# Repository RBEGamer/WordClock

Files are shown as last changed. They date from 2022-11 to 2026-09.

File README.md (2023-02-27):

# Wordclock

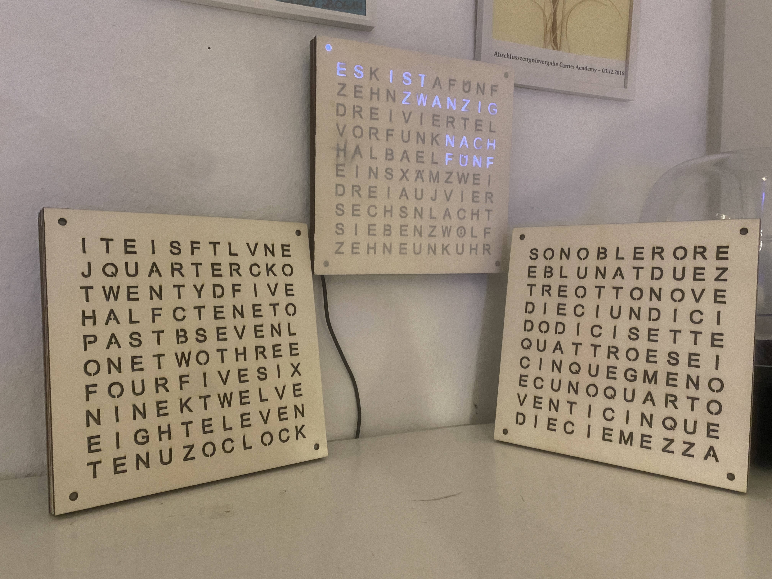
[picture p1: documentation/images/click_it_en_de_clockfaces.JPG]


## FEATURES
Simple easy to build tabletop wordclock with many features:

* different clockfaces and languages
* different colormodes (coldwhite, warmwhite, 2x rainbow)
* RP2040 based
* ambient light sensor
* temperature sensor
* eu summertime support
* optional wifi based sync and control

## IMPLEMENTED LANGUAGES

* GERMAN
* ENGLISH
* ITALIAN

### POSSIBLE LANGUAGES

* SPANISH
* DUTCH

## USER-MANUAL

complete

### POWER UP

Connect the clock using its Micro-USB port on the back a USB power source like a PC or USB wallplug.
After a few seconds the clock lights up, depending on the configuration it may be that the brightness is set very low or the fontface is set incorrectly. To make these settings the web configuration can be used. Please follow the steps below to access the configuration webui.

### CONNECT CLOCK TO WIFI

To sync up the current time using NTP or setup the fontface or colors, connect the clock to a existing 2.4Ghz Wifi network.
After startup the clock check if the previous setup network exists. 

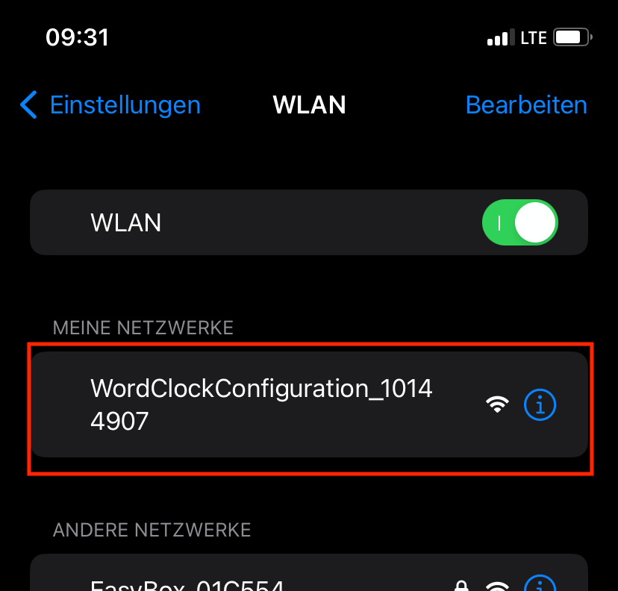
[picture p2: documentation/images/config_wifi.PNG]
config_wifi


If not, the clock will open its own Wifi with the SSID `WordClockConfiguration_%ID%` (`%ID%` is the ID printed on the back of the clock).
After connecting, an captive portal should open, or by open the IP `192.168.4.1` in a web browser to set up the new Wifi.

**NOTE**
The configuration wifi will be disabled after one minute, so if it is not visible power cycle the board.

**NOTE**
If the clock cannot connect to the configured WLAN (not found, or invalid credentials,...), the configuration accesspoint is opened again.

### ACCESS CONFIGURATION WEBUI

After configuring the wifi, you can access the clock-configuration webpage using its DHCP address (see your router or nmap) or use the clocks mDNS adress `http://wordclock%%ID%%.local` with `%%ID%%` is the ID printed on the back of the clock, like: `http://wordclock10144907.local`.

**NOTE** After a wifi connection is established (power up, power cycle), the clock shows it on its display by means of the words. here the ip blocks are shown with the hours and the dot by using dark switching 0 or 12.

So `192.168.178.4` results in the following word order:
`one nine two  (pause)(dark 0/12)(pause) one six eight (pause)(dark 0/12)(pause) one seven eight (pause)(dark 0/12)(pause) four`

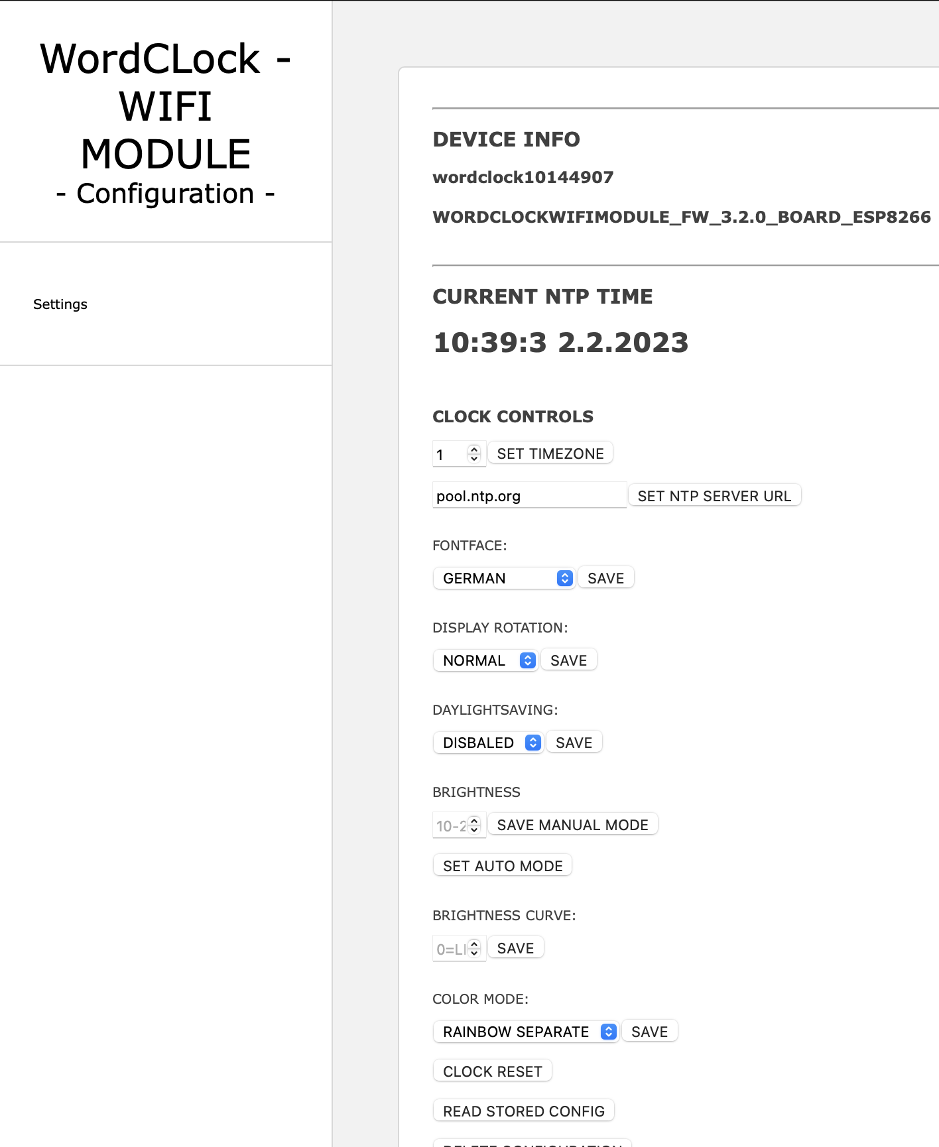
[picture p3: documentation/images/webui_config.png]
webui_config


### FIRMWARE UPDATE

It is possible to update the software of the clock.
This adds new features like new languages and general bug fixes.
The software of the `RP2040` main processor can be updated directly via the USB interface on the back.
To perform the update, a small button called `QBOOT` must be pressed and held while the watch is turned off and connected to a PC.

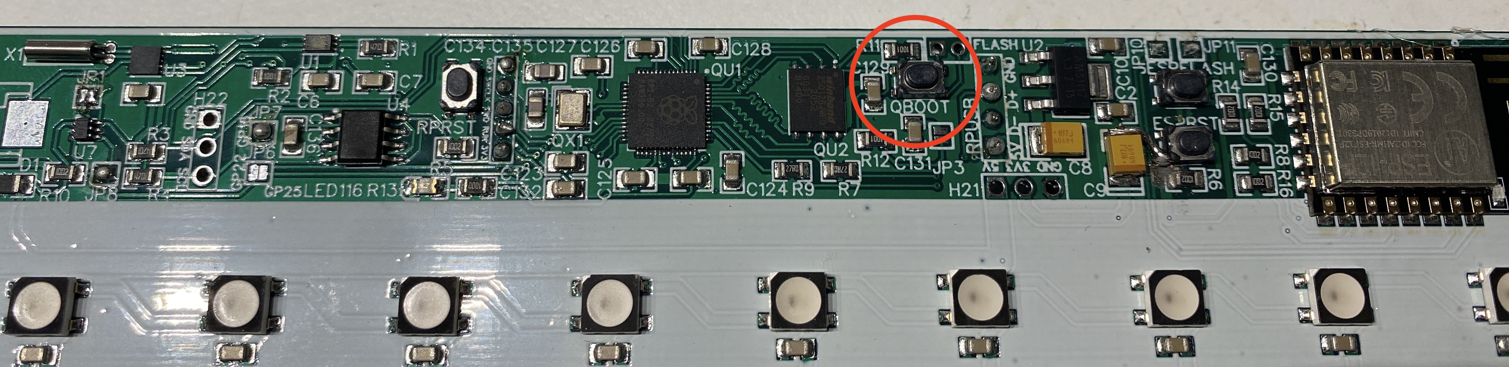
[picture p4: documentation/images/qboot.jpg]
qboot_button


You can press the button even when the clock is assembled.
The button is accessible through the cutout on the top of the clock near the USB port.

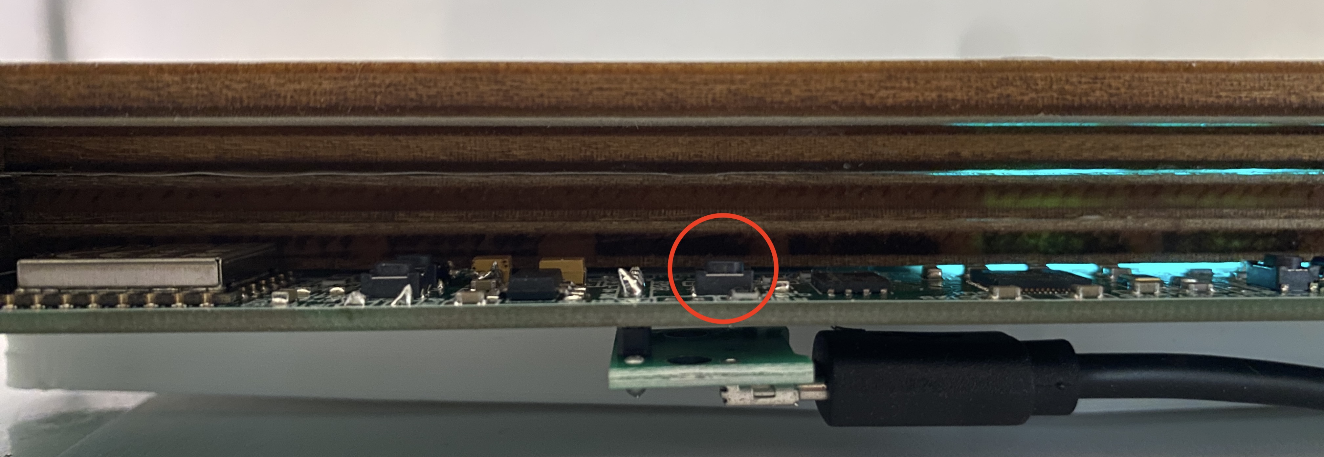
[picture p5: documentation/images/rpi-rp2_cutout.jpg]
rpi-rp2_cutout


Now a new removable drive with the name `RP-BOOT` should appear.
Now copy (or drag&drop) the `.u2f` update file to the drive.
After the copy process is complete, the drive disappears automatically and the clock restarts.
If the update fails, you can do it again by repeating the steps.

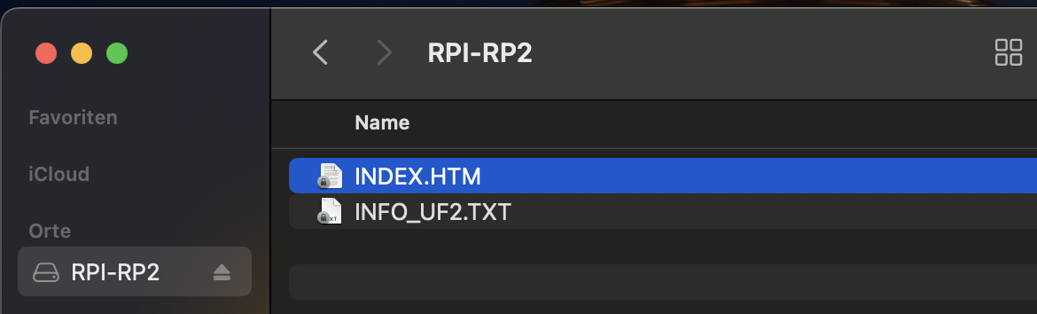
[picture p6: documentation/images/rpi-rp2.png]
rpi-rp2


**NOTE**
Check the firmware version after an update using the [STATUS-CODES](#status-codes).

**NOTE**
On MacOS drag&drop installation can fail, so please try `$ cp ./WORDCLOCK_Vx_RP2040_x.y.z_Release.uf2 /Volumes/RPI-RP2/` from the Terminal-App instead.

**NOTE**
Instead of reconnecting the USB cable, there is an other button called `RPRST` which can be pressed once, while keep holding the `QBOOT` button.

#### DOWNLOAD FIRMWARE UPDATE
Please identfy the clock hardware version, which is printed on the back of the clock or use the [STATUS-CODES](#status-codes) display.

##### STATUS CODES
Directly after startup, the clock shows some version information about the hardware revision and used software.
This information is language-independent and is displayed in the form of individual illuminated LEDs.
On the following picture their meaning can be determined.

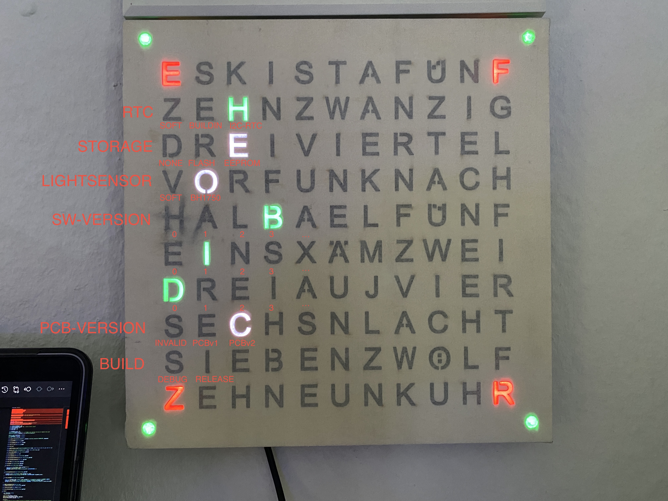
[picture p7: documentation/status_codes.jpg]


Information from example above:

* Hardware-Revision: 2 (`PCBv2`) so use `WORDCLOCK_V2_*.uf2` firmware files
* RTC: `I2C (DS17307)`
* Configuration-Storage: `EEPROM`
* Lightsensor: `BH1750`
* Software-Version: 3.1.0 (test), please use stable `Release` firmware

To download the latest software, please see the [Firmware-Releases](https://github.com/RBEGamer/WordClock/releases) page.
For the current `V2` clocks, use the latest firmware file: `WORDCLOCK_V2_RP2040_RP2040RTC_x.y.z_Release.uf2`.

For the `V1` clocks, use the archived firmware: `WORDCLOCK_V1_RP2040_3.1.0_Release.uf2`.

**Note**
If `RTC`, `Lightsensor` and `Storage` are set to `SOFT` and `None`/`FLASH` please use firmware `WORDCLOCK_Vx_NOI2C_*.u2f`.
* RTC: `SOFT`
* Configuration-Storage: `FLASH` or `NONE`
* Lightsensor: `SOFT`

[WORDCLOCK_V2_RP2040_NOI2C_3.2.2_Release.uf2](https://github.com/RBEGamer/WordClock/releases/download/v3.2.2/WORDCLOCK_V2_RP2040_NOI2C_3.2.2_Release.uf2)

### FIRMWARE CUSTOMIZATION

It is also possible to make your own adjustments to the clock's firmware, e.g. to add your own languages or animations.

It is recommended to use Visual Code with the following plugins as the editor, since the project already has all the necessary settings and also a debug environment configured. This makes it easy to get started.

* `C/C++` by `Microsoft`
* `Cortex-Debug` by `marus25` 

The complete firmware of the RP2040 main processor is available in the `src/base/wordclock/src` folder.
If you want to develop your own fontface, see the examples in  `wordclock_faceplate` and the `wordclock_faceplate_template.*` files.

#### BUILDING THE FIRMWARE YOURSELF

```bash

$ git clone --depth 1 https://github.com/RBEGamer/WordClock.git ~/WordClock
$ cd ~/WordClock/base/wordclock/
# UPDATE CMAKE PATHS
$ rm -Rf build CMakeCache.txt CMakeFiles elf2uf2 generated pioasm WORDCLOCK_* build_u2f
# see board folder for available PCB-Revisions
# for example to build the firmware for a PCBv2 use WORDCLOCK_V2_RP2040_RP2040RTC
## RELEAE
$ cmake -DCMAKE_BUILD_TYPE=Release -DWORDCLOCK_BOARD=WORDCLOCK_V2_RP2040_RP2040RTC .
## DEBUG
$ cmake -DCMAKE_BUILD_TYPE=Debug -DWORDCLOCK_BOARD=WORDCLOCK_V2_RP2040_RP2040RTC .
PICO_SDK_PATH is ~/WordClock/src/base/pico-sdk
Defaulting PICO_PLATFORM to rp2040 since not specified.
Defaulting PICO platform compiler to pico_arm_gcc since not specified.
PICO compiler is pico_arm_gcc
-- The C compiler identification is GNU 10.3.1
-- The CXX compiler identification is GNU 10.3.1
-- The ASM compiler identification is GNU
-- Found assembler: /opt/homebrew/bin/arm-none-eabi-gcc
Build type is Release
PICO target board is WORDCLOCK_V2_RP2040_RP2040RTC.

# BUILD
# on first build the pico-sdk will be downloaded
# the result should be a WORDCLOCK_V2_RP2040_RP2040RTC_3.2.3_Debug.uf2
$ make -j8
[ 97%] Linking CXX executable WORDCLOCK_V2_RP2040_RP2040RTC_3.2.3_Debug.elf
[100%] Built target wordclock

# FLASH
# you can use the drag&drop method to install the firmware or use the pico-tool with a usb connected clock.
# see flash_release.sh or flash_release.sh
$ ../picotool/picotool load -f *.uf2 && ../picotool/picotool reboot
```

**NOTE**
To build the a new firmware relase, for all clock hardware-revisions you can use the `build_all.sh` script.
It builds the `.u2f` for each board definition located in the `board` folder and stores the build artefacts in `build_u2f`.

## BUILD YOUR OWN CLOCK

### PARTS

The latest version of the clock is currently `v2` so please replace `vX` with `v2` in the following instructions.

#### ELECTRICAL

* 1x ASSEMBLED PCB - `./src/pcb/vX`
* 1x MicroUSB to DIP breakout or USB Cable with open leads

#### MECHANICAL

##### LASERCUT LAYERS 
**See `./src/lasercut` for cutting instructions**

All needed drawings are located in the `./src/lasercut/vX/layers_seperated` directory:

* 1x - BACKCOVER `3_backcover_layer` - >=3mm plywood (or plexiglas)
* 1x - SPACER `2_lightguide_layer` - >=3mm plywood (or plexiglas, but its hidden)
* 1x - SPACER `2_lightguidehexnut_layer` - >=3mm plywood (or plexiglas, but its hidden)
* 1x - FACEPLATE `1_text<LANGUAGE>_layer` - plexiglas, plywood >220x220mm 1mm

##### [OPTIONAL] 3D PRINTED STANDS

All needed files are located in the `./src/3d_print/` directory:

####### TABLESTAND
* 1x - TABLESTAND `wordclock_tablestand.stl`

####### WALLMOUNT
* 1x - WALLMOUNT `wordclock_wallmount.stl`

#### OTHER

* sandwich paper - as additional semi transparent diffusor ontop of the leds
* woodglue - to glue spacers together
* isopropanol - plexiglas cleaning before gluing

#### TOOLS

* lasercutter / cnc for cutting wood / plexiglas with working-area of at least 220mmx220mm
* 3d rpinter can be used to print the faceplates and spacers(conversion from svg-> 3mm stl is needed)

#### ASSEMBLY INSTRUCTIONS

##### 0 - INSERT HEXNUTS
Place some M4 nuts in the hexnut cutouts in the `lightguidehexnut` plate.
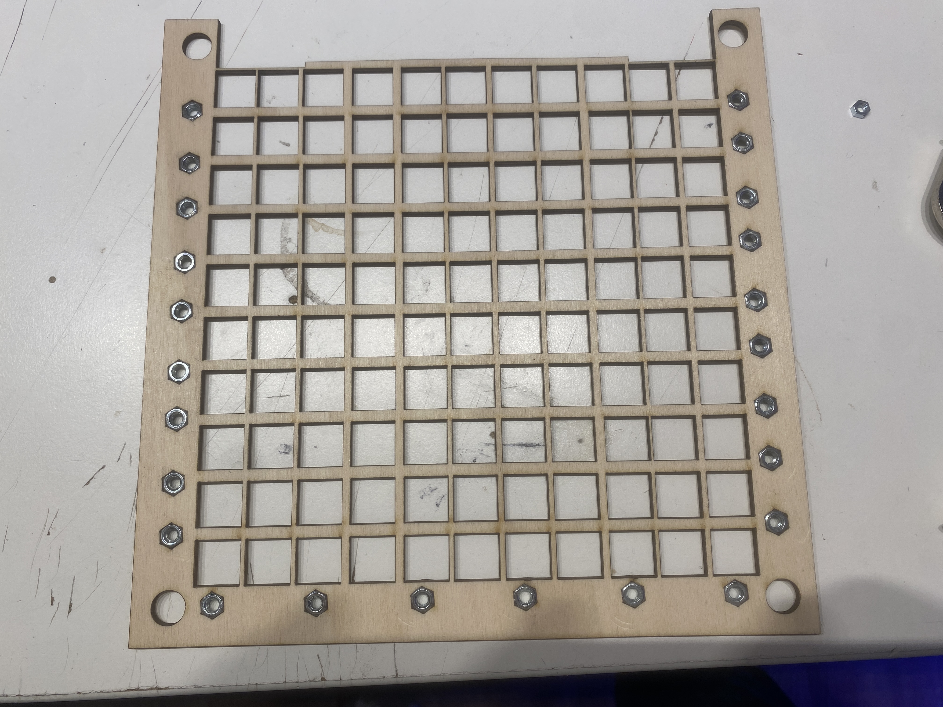
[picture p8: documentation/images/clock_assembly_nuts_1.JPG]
clock_assembly_nuts_1


##### 1 - GLUE SPACERS TOGEHTER
Glue the spacers `lightguidehexnut` and `lightguide` using woodglue togehter.
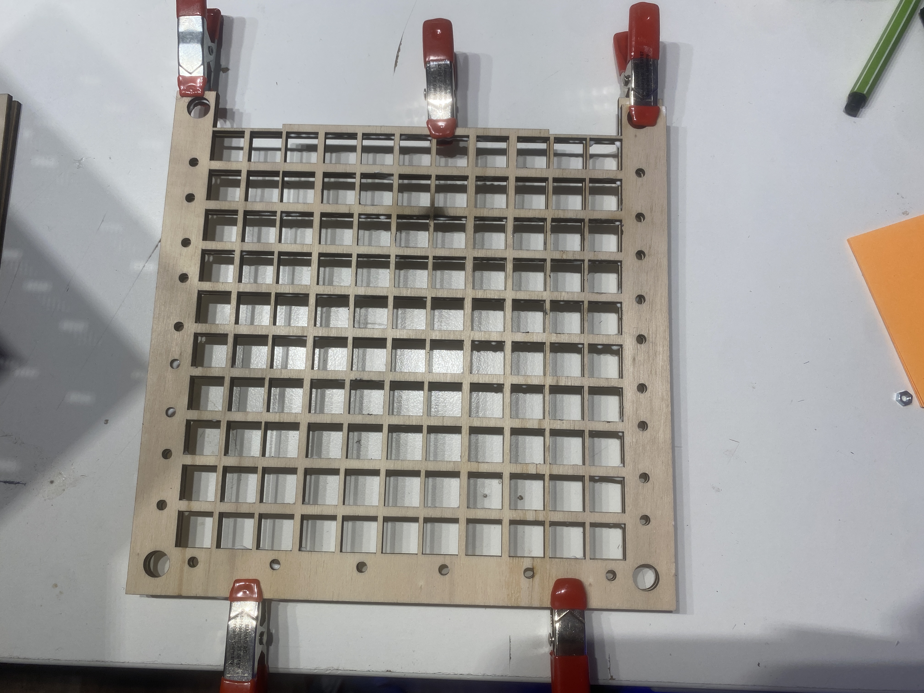
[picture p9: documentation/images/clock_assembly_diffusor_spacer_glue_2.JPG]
clock_assembly_diffusor_spacer_glue_2


##### 2 - ADD  DIFFUSOR
Place and glue the sandwichpaper ontop the the `lightguidehexnut` layer.
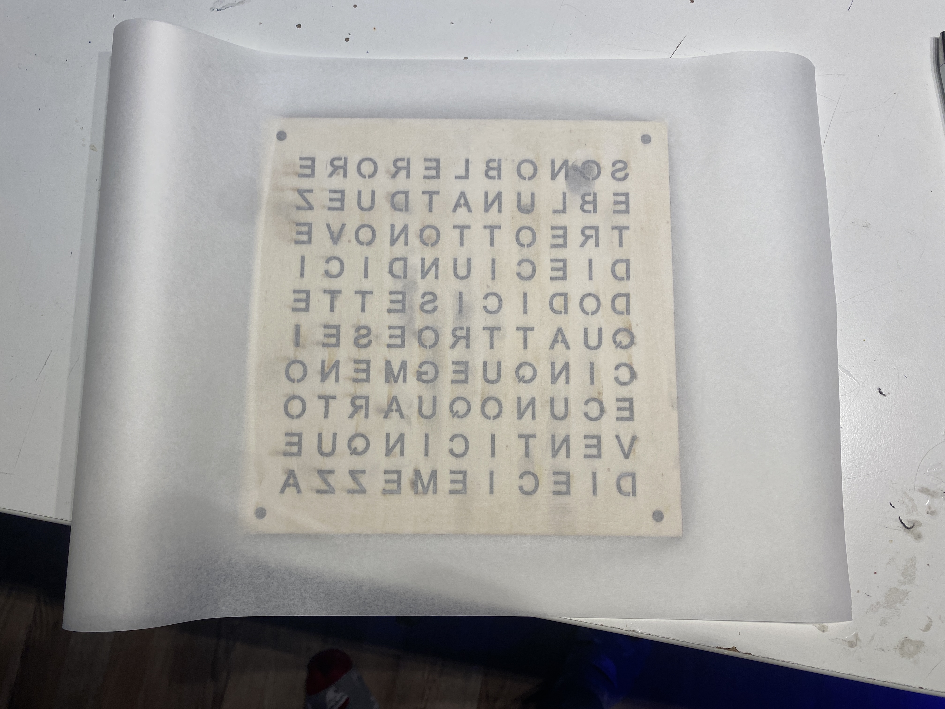
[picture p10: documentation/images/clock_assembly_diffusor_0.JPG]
clock_assembly_diffusor_0

 
##### 3 - ADD FACEPLATE
Glue the `FACEPLATE` ontop of the sandwhichpaper, make sure that the cutout in the spacers is the top of the clock.
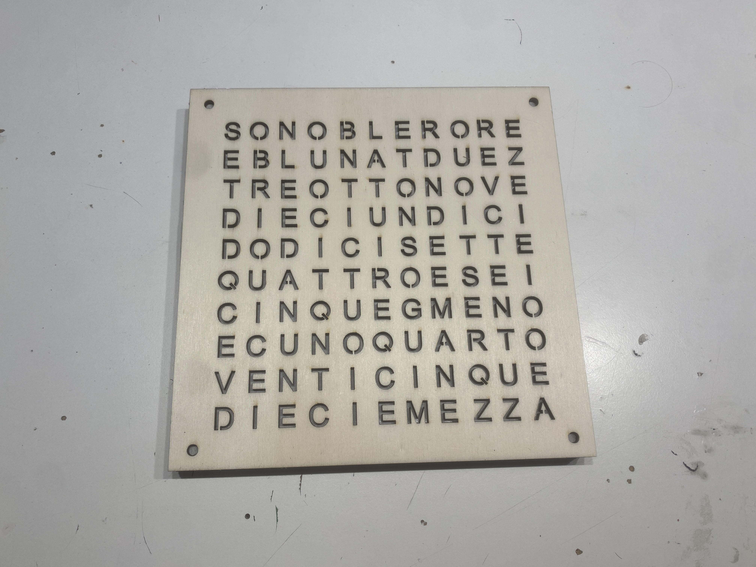
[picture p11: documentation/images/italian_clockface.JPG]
italian_clockface


##### 4 - ASSEMBLY
Place the glued fontplate/spacer assembly ontop of the PCB and place the `BACKCOVER` on the back of the PCB.
Use the four M4 screws in the holes in the corners, to screw anything together.
clock_assembly_diffusor_0

##### 5 - WALLMOUNT / TABLESTAND [OPTIONAL]

Mount the 3D-printed `wallmount` or `tablestand`.

###### TABLESTAND
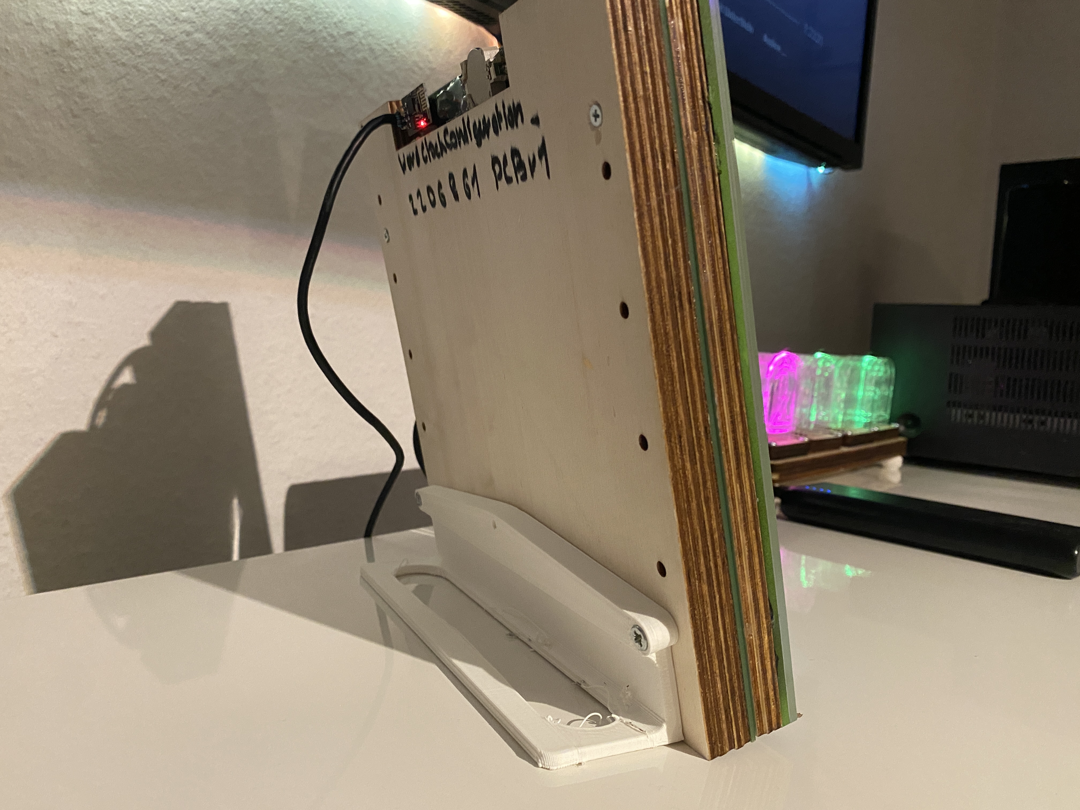
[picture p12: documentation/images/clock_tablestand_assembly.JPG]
clock_tablestand_assembly


###### WALLMOUNT
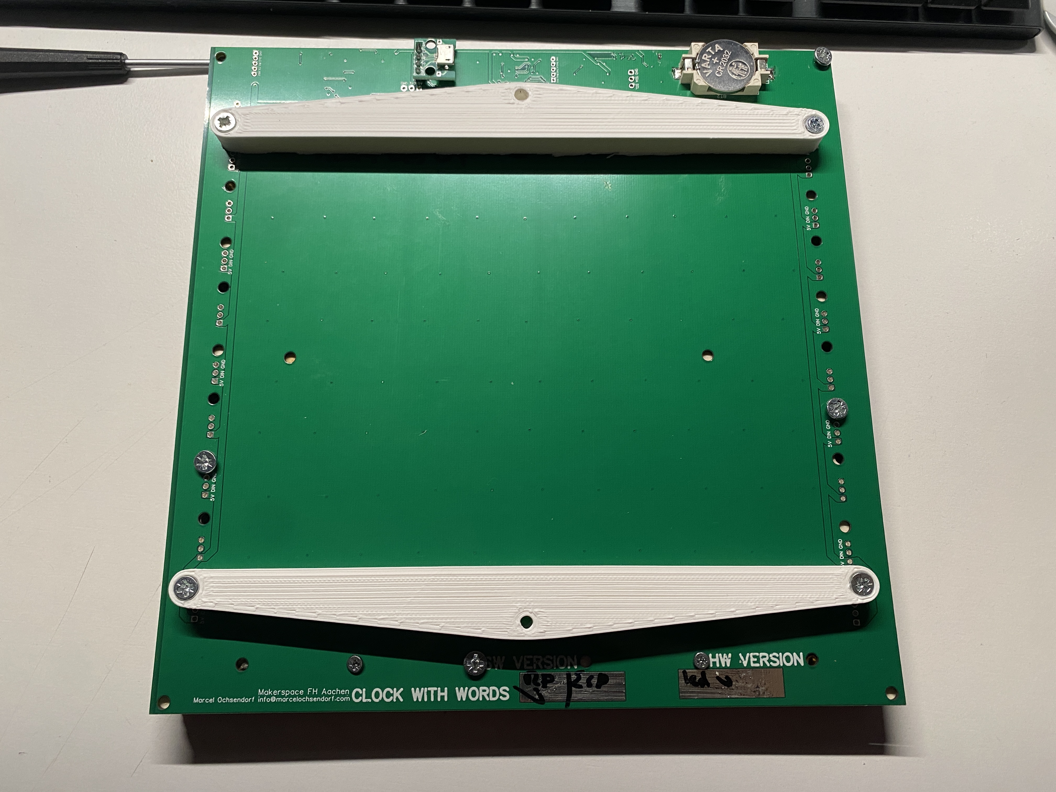
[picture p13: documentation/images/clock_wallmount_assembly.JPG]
clock_wallmount_assembly


##### 6

Flash the firmware to the clock using the [USER-MANUAL](#user-manual)

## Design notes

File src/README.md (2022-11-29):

# SRC

* `base` - main RP2040 software
* `pcb` -  pcb with 11x10 led matrix
* `lasercut` - all lasercut files (`svg`, `dfx`), cad files
* `wifiextention` - softeare for `esp8266` wifimodule

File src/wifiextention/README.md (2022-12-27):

# WIFIMODULE - ESP8266 SOFTWARE

This folder contains the software for the optional `ESP8266-12F` (PCBv2) or `ESP8266-01` (PCBv1).
Also compatible with `ESP32`.
The module allows to edit settings and sync time over a ntp server.

Copy the content of the `3rd_party` folder into the `Arduino`-Libraries folder.

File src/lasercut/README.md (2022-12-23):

# LASERCUT

## PCBv1

Glue the wooden pieces together in the following order: 

* 1x - `drawing_chars`
* 3x - `drawing_lightguide`
* `--- PCB ---`
* 2x - `drawing_back`

## PCBv2

the V2 lasercutting files are loacated in the `./v2` folder.
The main source files is the single `drawing.svg` file, which contains several numbered layer object in it.
Objects in `[]` can be ignored, these are used for reference linke the `[PCBv2]` image of the PCB.

Each layer object in the svg will be used to cut one piece for the clock.
Some layers are needed multible times and will be glued together to form a higher single layer.

### FACEPLATE (PLEXIGLAS)

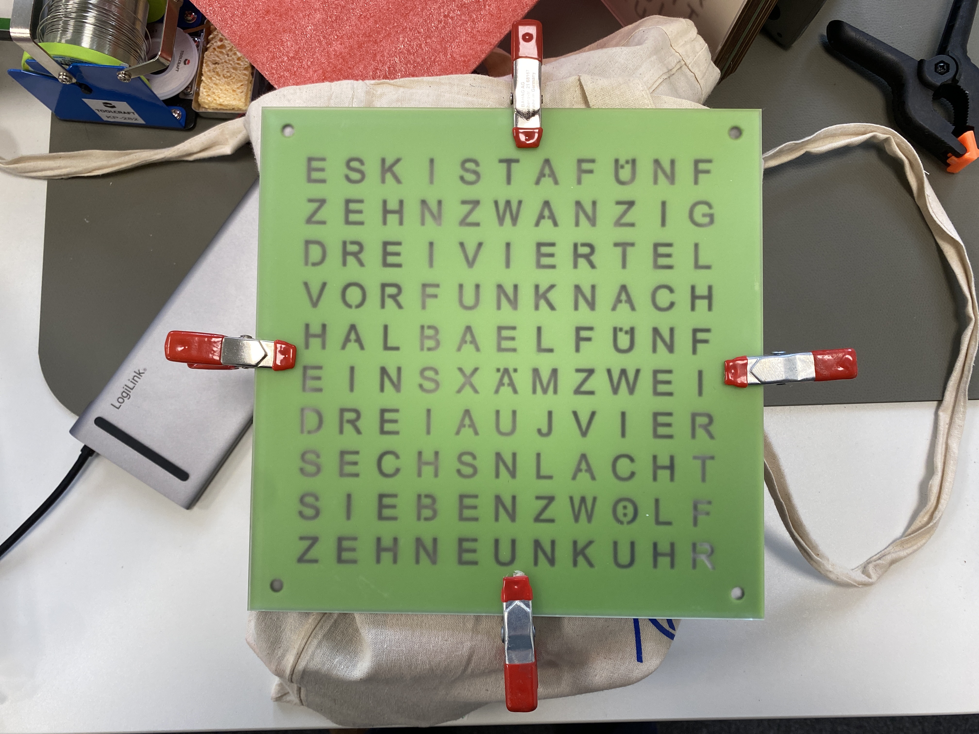
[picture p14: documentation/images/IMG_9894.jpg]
topcover


* 1x - `0_opaque_layer` - this is the semi-transparent toplayer plexiglas
* 1x - `1_<LANGUAGE>_layer` - this is the textlayer with the cut out characters

 Clean (isopropanol), place and clamp! the `0_opaque_layer` and `1_<LANGUAGE>_layer` layer ontop of each other and use the `ACRIFIX Plexiglas glue` to fill the minute dot holes with the glue and let it dry for at least 8h.

### LIGHTGUIDE (WOOD)

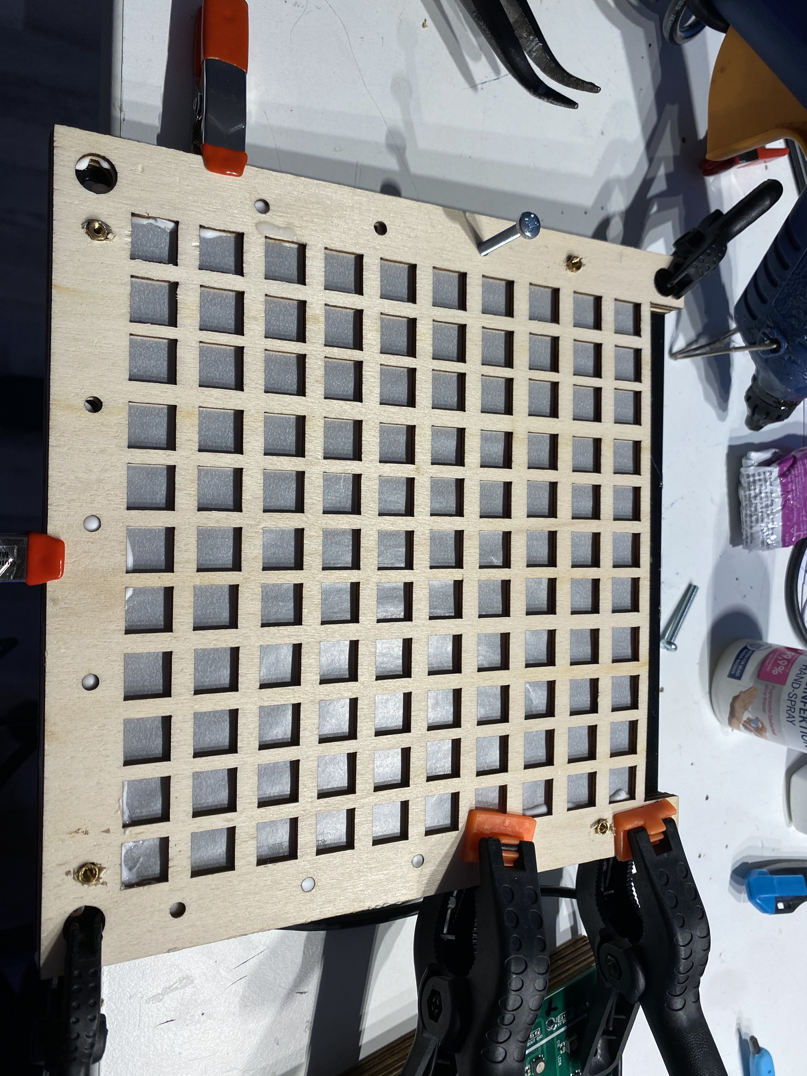
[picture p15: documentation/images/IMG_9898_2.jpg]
lightguide


* 1x - `2_lightguidehexnut_layer` - its use to get some space between the leds and the text faceplate
* 2x - `2_lightguidenormal_layer` - its use to get some space between the leds and the text faceplate

Glue the two `2_lightguidenormal_layer` sheets together and before adding the third one add one sheet of sandwich paper/ semi transparent diffusor between them.
In the end this additional diffusor sit ontop of the leds with one lightguide seperating them.
You can place screws in the holes to align everything during curing.

### BACKCOVER

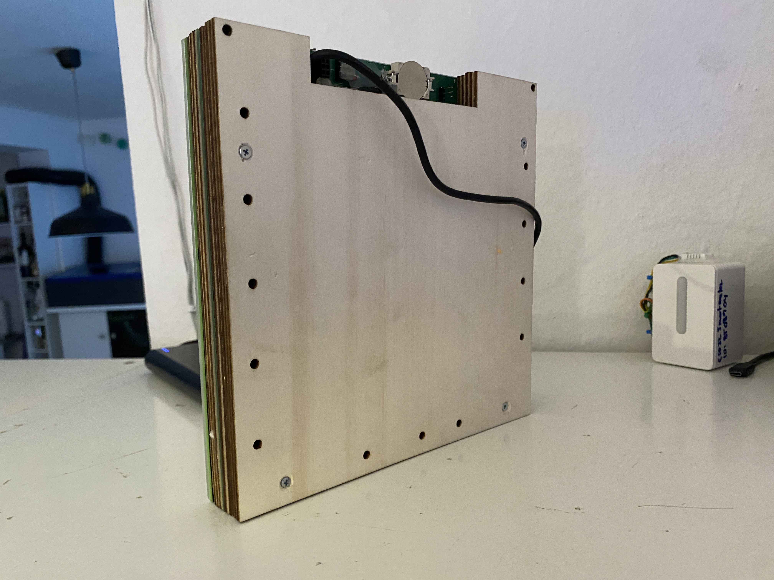
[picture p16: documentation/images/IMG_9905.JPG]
backcover


* 1x - `3_backcover`

## STACK

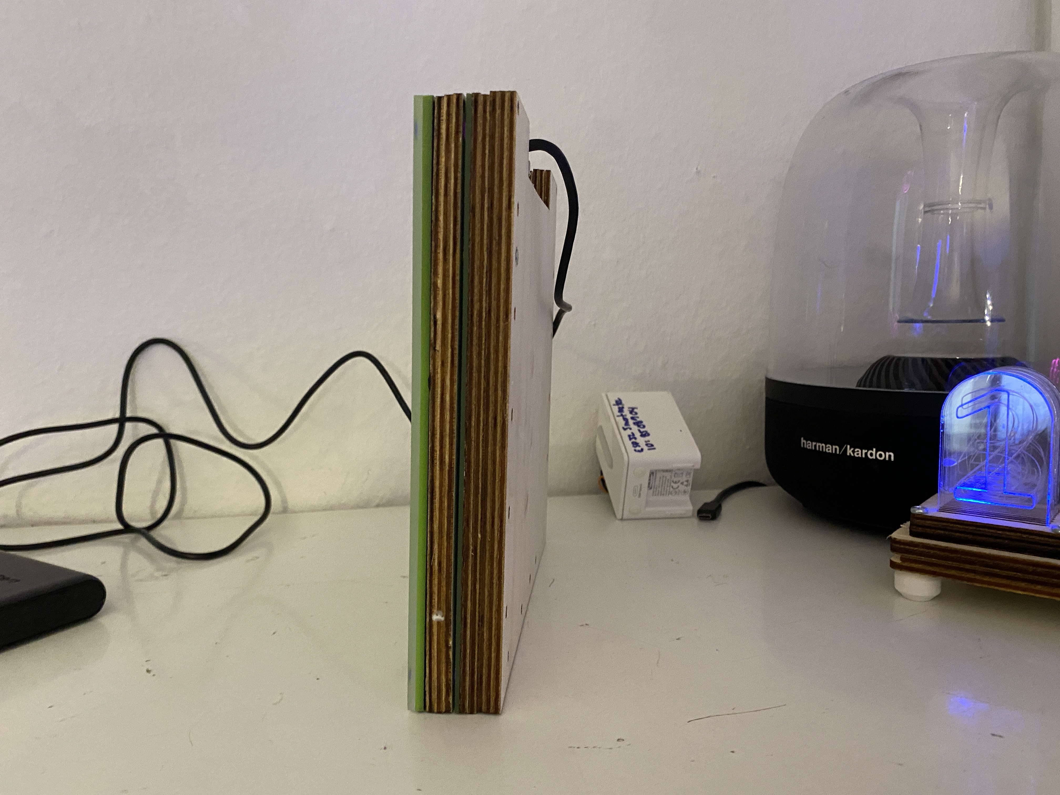
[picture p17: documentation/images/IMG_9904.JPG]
stack


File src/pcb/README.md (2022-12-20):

# PCB

## V1

The first revision of the wordclock pcb is working but has some issues!
Please see PCB version 2, with all fixed issues and further features.

### ISSUES

* r12 produces flash issues
* esp8266-01 creates space issues with usb connector
* levelshifter for ws2812 not working relilable with 800khz
* rtc not readlable for i2c, power issue => can be resolved by connecting VCC of the DS1307 chip to 5V.

### JUMPER SETTINGS

In order to make this version of the pcb compatible with the current firmware version, please use the following jumper settings:

* !!! REMOVE TRANSISTOR Q2 !!!
* !!! REMOVE RESISTOR R12 !!!
* bridge JP1
* bridge JP7 (GP16)
* jumper H23 (middle+upper, near JP2)

### WIFI-MODULE

If you want to use the ESP8266-01 you have to put a missing 10K (or bridge) the pins VCC and EN (CH-PD) on the module in order to enable the module.
This resistor is missing on the PCB.

## V2

### CHANGES

* replace ds1307 with pcf85263a
* remove R12 (resolve flash access issues)
* added esp8266-12f (replacement for esp8266-01)
* removed transistor base levelshifter (replaced with txb0101)
* added rpi rst pullup (optional)
* moved coincell to toplayer
* added loadcaps 10pf for 12mhz osc
* added rst/run to swd connector
* removed german wordclock faceplate from the back of the pcb
* added i2c eeprom to avoid flash as settings store

### JUMPER SETTINGS

* JP10 -> ESP_TX
* JP11 -> ESP_RX
* JP7 -> GP16
* (JP1) -> TBX01-OE  
* JP6 -> GP22

Use `WORDCLOCK_V2_RP2040.h` with this jumper settings:

* JP7
* JP1
* JP8
* JP10
* JP11

## ISSUES

* with the current v2 lasercut part the position of C121 is not ideal
* led alignment is not perfect on left/right lines (check with svg)

* esp rst flash buttons arent connected with gnd...
* flash header not 2.54
* tx01 not working

## TODO 

* remove jp4, d1, add button to gpio22 instead of jp6
* add bigger soldermask field for mac address
* white skilkscreen
* bridge jumper per default

## V3

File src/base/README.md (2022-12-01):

# BASE - MAIN RP2040 SOFTWARE

This folder contains the software for the rp2040 on the board.

* `wordclock` - main source
* `pico-sdk` - unmodified pico-sdk, used by `wordclock`
* `picotool` - picotool to flash `.u2f` file to pico (useful for mac)

Here all basic functionalities are implemented such as:

* Clockfaces: e.g. German, English, Binary, Dotted
* LED Matrix control
* Sensor interface
* wifimodule communication 

## BUILD

## FOR LATEST PCB VERSION
```bash
$ cd ./wordclock
$ cmake .
$ make
```

## SELECT BOARD: PCBv1

To select a different board configuration, thee the `wordclock/board/` folder.
This folder contatins a configuration for each PCB version.

To set the board, edit the `wordclock/CMakeLists.txt` and set `19 | set(PICO_BOARD "WORDCLOCK_V1_RP2040")` to the board filename without suffix.

### OR USING A COMMANDLINE SWITCH

```bash
$ cmake -DPICO_BOARD=WORDCLOCK_V1_RP2040 .
```

## FLASH

```
# RP2040 IN DFU MODE
$ ./picotool load ./wordclock/wordclock.u2f
$ ./picotool reboot
```

## SERIAL COMMANDS

These commands will be used by the wifi-module.
The basic command structure uses a key_value_crc approch.
See `./wordclock/src/wifi_interface.cpp` for bidirectional reference implementation.

```
# <COMMAND>_<VLAUE>_<CRC16 (from command+value with poly=0x8408)>
```

### POSSIBLE COMMANDS

* `st` - set time with value: `hh:mm:ss`
* `sb` - set brightness: `1-255` fixed or `0` for automatic
* `fp` - frontplate: `0`(GERMAN), `1`(ENGLISH), ... (see `enum class FACEPLATES` in `wordclock_faceplate.hpp`)
* `fd` - flip displaz: rotate the display 180 drg `0`(normal, lightsensor top) or `1`
* `ip` - show ip string (used to indicate wifimodule ip) `192.168.0.1`

## DEBUGGING

All serial commands send through the serial pins `0`, `1` of the rp2040 will be mirrored to the USB-CDC connection.
For advanced debugging use the SWD `RPSWD - P1` connector on PCBv2, to connect a Picoprobe or J-LINK.

## ADDING CUSTOM FACEPLATES

The current software implementation is very flexible in order to add new faceplates.
There are two template files provided with a simple implementation of a clockface.

* `./wordclock/src/wordclock_faceplate_template.hpp`
* `./wordclock/src/wordclock_faceplate_template.cpp`

Please see reference implementation for a word-base clockface:

* `./wordclock/src/wordclock_faceplate_german.hpp`
* `./wordclock/src/wordclock_faceplate_german.cpp`

If you dont have words on your fontface and wanto to implement other stlyes (like random dots, binary, for fancy animations), see the reference implementation for a dot based clockface:

* `./wordclock/src/wordclock_faceplate_dots.hpp`
* `./wordclock/src/wordclock_faceplate_dots.cpp`

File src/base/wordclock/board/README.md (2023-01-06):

# board

This folder contains custom rp2040 wordclock board definitions:

* **WORDCLOCK_V1_RP2040 - first pcb version with some flash and pullup errors with timing modifications (see FLASH section)

* **WORDCLOCK_V2_RP2040 - second pcb version with i2c eeprom and proper rtc and esp8266-12F **different led configuration**

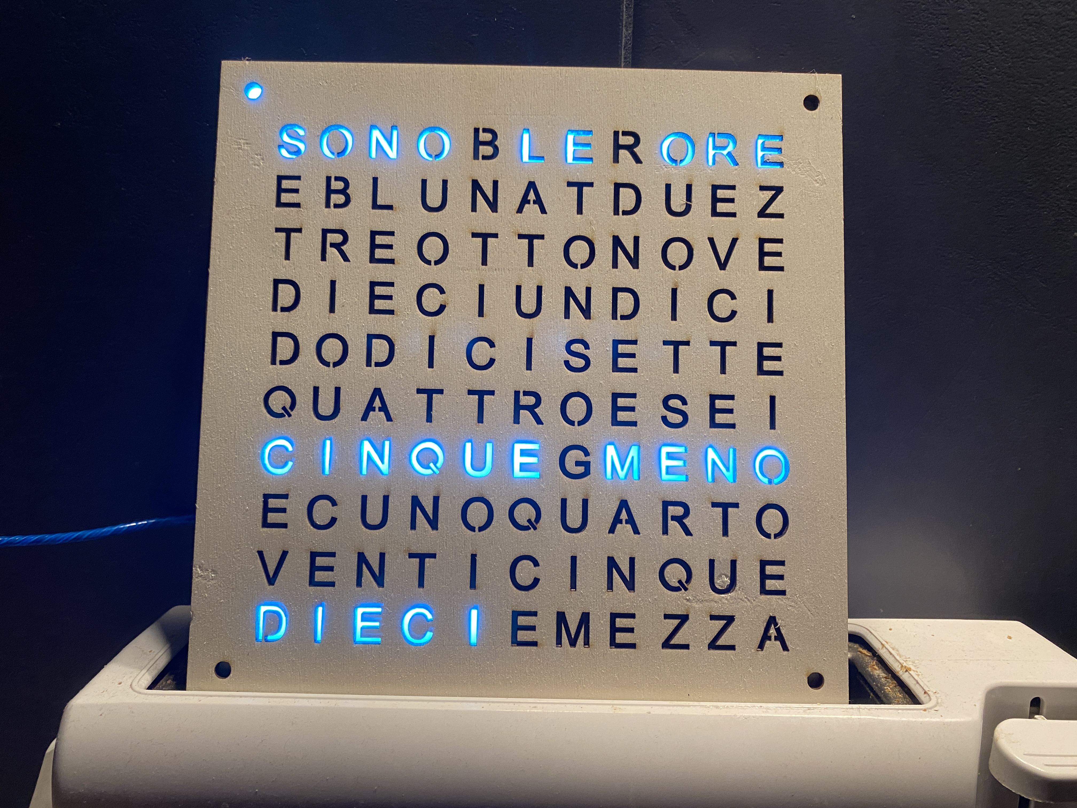
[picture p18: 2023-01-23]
documentation/images/colormode_rainbowequal.JPG

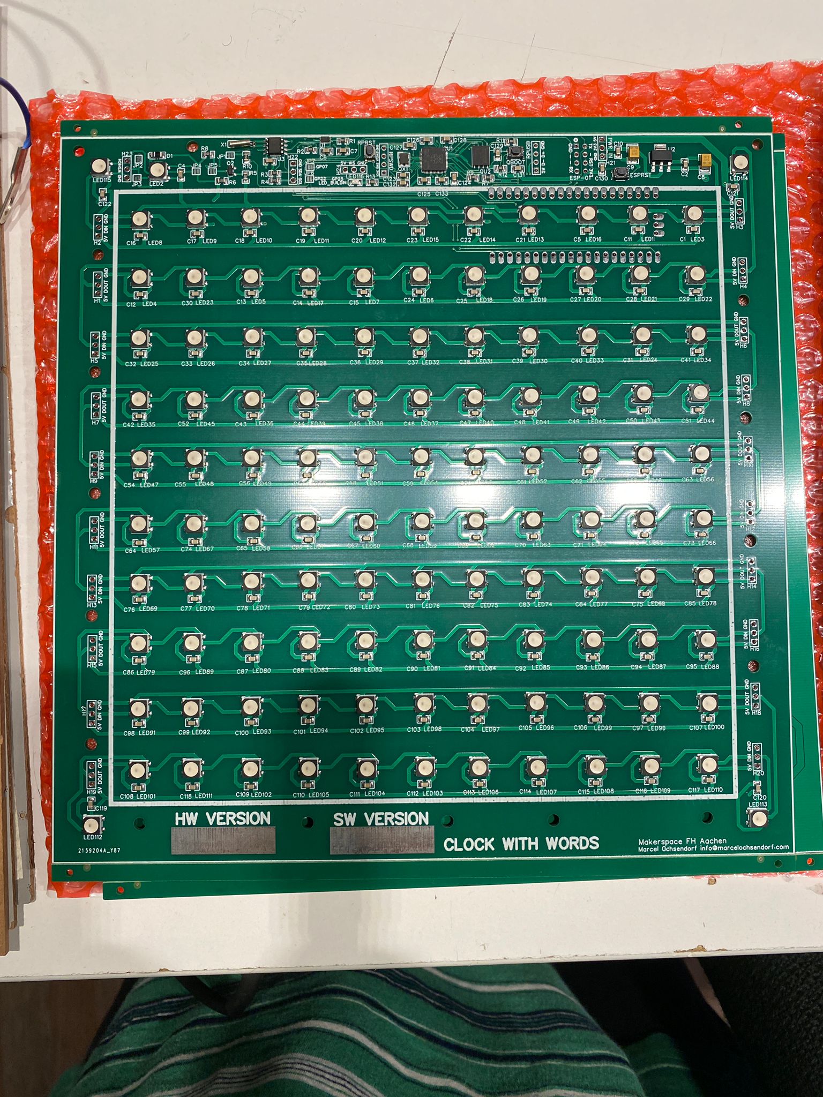
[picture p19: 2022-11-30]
documentation/images/2dbacd49-3fb6-4a4f-8a37-d2d7a210fdaf.jpg

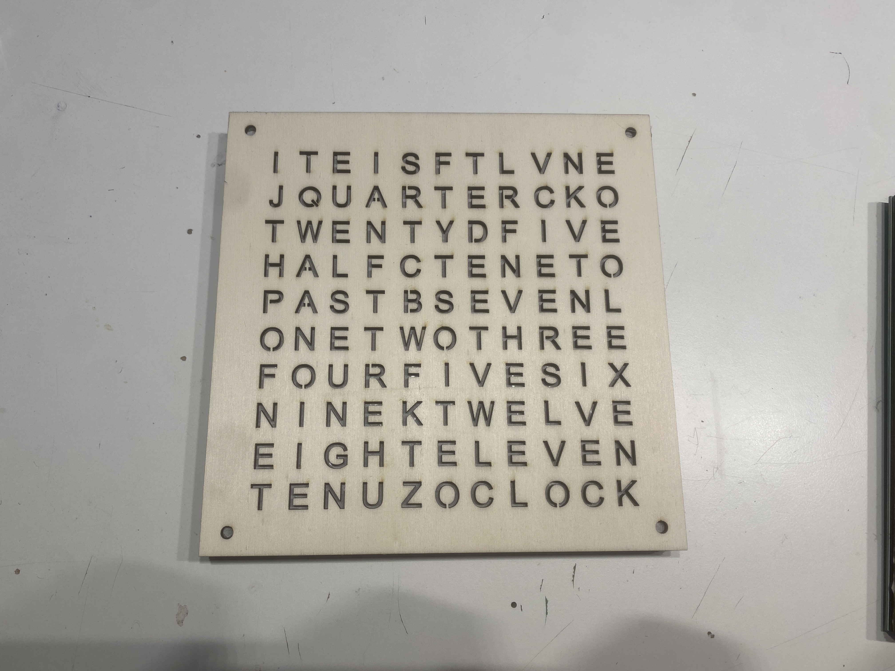
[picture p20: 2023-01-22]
documentation/images/english_fontface.JPG

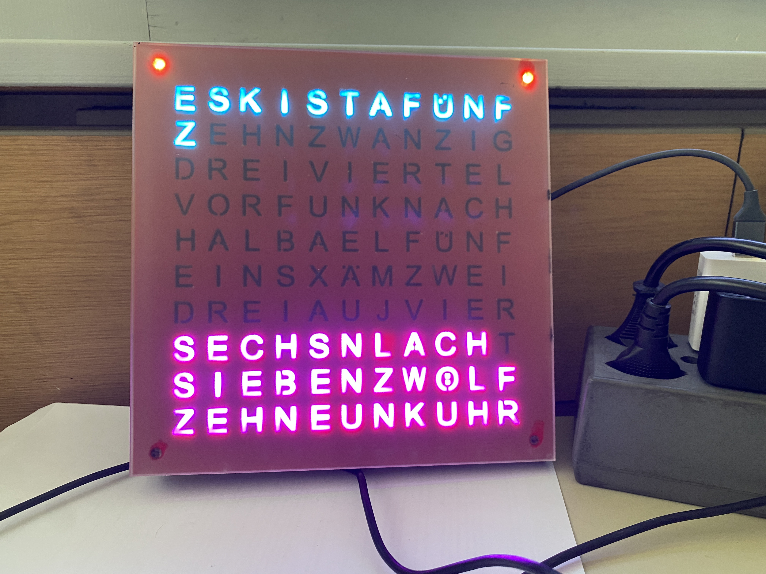
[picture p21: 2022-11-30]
documentation/images/IMG_9979 Kopie.jpg

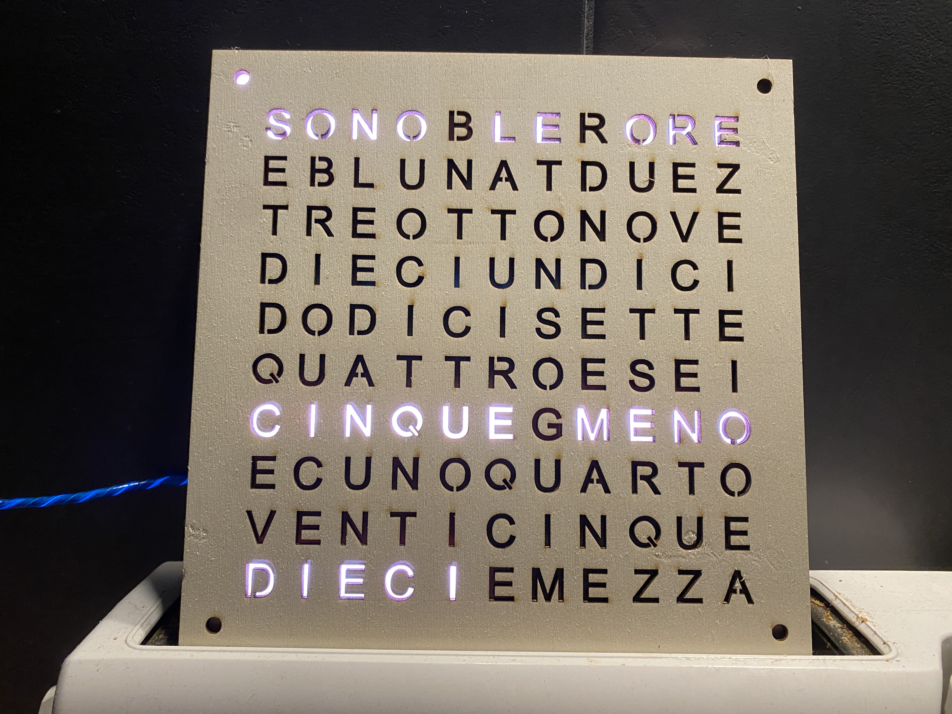
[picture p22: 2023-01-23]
documentation/images/colormode_warmwhite.JPG

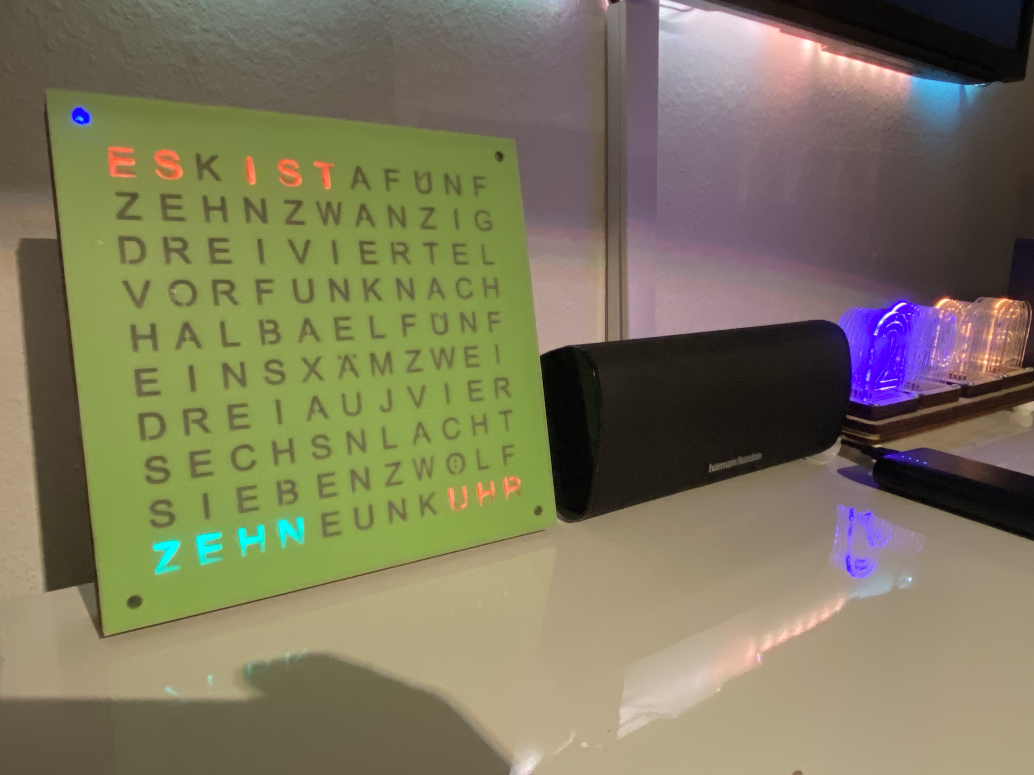
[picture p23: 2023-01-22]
documentation/images/clock_tablestand_mounted.JPG

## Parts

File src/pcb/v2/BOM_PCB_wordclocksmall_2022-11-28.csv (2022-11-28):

ID | Name | Designator | Footprint | Quantity | Manufacturer Part | Manufacturer | Supplier | Supplier Part | Price
1 | TXB0101DCKR | U7 | SC-70-6_L2.2-W1.3-P0.65-LS2.2-BR | 1 | TXB0101DCKR | Texas Instruments | LCSC | C324081 | 0.593
2 | PCF85263ATL/AX | U3 | DFN-10_L2.6-W2.6-P0.50-BL-EP | 1 | PCF85263ATL/AX | NXP(恩智浦) | LCSC | C2651523 | 2.549
3 | 27Ω | R7,R9 | R0805 | 2 | 0805W8F270JT5E | Ever Ohms Tech | LCSC | C17594 | 0.002
4 | 10pF | C134,C135 | C0805 | 2 | CL21C100JBANNNC | YAGEO | LCSC | C1785 | 0.014
5 | 100nF | C136,C131,C132,C133,C130,C123,C124,C125,C126,C127,C128,C129,C6,C7,C42,C43,C44,C45,C46,C47,C48,C49,C50,C51,C52,C53,C54,C55,C56,C57,C58,C59,C60,C61,C62,C63,C64,C65,C66,C67,C68,C69,C70,C71,C72,C73,C74,C75,C76,C77,C78,C79,C80,C81,C82,C83,C84,C85,C86,C87,C88,C89,C90,C91,C92,C93,C94,C95,C96,C97,C98,C99,C100,C101,C102,C103,C104,C105,C106,C107,C108,C109,C110,C111,C112,C113,C114,C115,C116,C117,C118,C119,C120,C121,C122,C12,C13,C14,C15,C24,C25,C26,C27,C28,C29,C30,C31,C32,C33,C34,C35,C36,C37,C38,C39,C40,C41,C11,C1,C2,C3,C5,C10,C16,C17,C18,C19,C20,C21,C22,C23 | 0805 | 131 | CC0805KRX7R9BB104 | YAGEO | LCSC | C49678 | 0.004
6 | PTS810SJM250SMTRLFS | ESPFLASH,RPRST,ESPRST,QBOOT | KEY-SMD_4P-L4.2-W3.2-P2.20-LS4.6 | 4 | PTS810SJM250SMTRLFS | C&K | LCSC | C116501 | 0.188
7 | 10K | R6,R8,R14,R15,R16,R5 | 0805 | 6 | 0805W8F1002T5E | UniOhm | LCSC | C17414 | 0.001
8 | M24C02-WMN6TP | U4 | SOIC-8_L4.9-W3.9-P1.27-LS6.0-BL | 1 | M24C02-WMN6TP | ST(意法半导体) | LCSC | C7562 | 0.137
9 | ESP-12F(ESP8266MOD) | U5 | WIFIM-SMD_ESP-12F-ESP8266MOD | 1 | ESP-12F(ESP8266MOD) | Ai-Thinker(安信可) | LCSC | C82891 | 2.311
10 | 1kΩ | R2 | R0805 | 1 | 0805W8F1001T5E | UniOhm | LCSC | C17513 | 0.002
11 | FC-2012HRK-620D | LED116 | LED0805-RD_RED | 1 | FC-2012HRK-620D | NATIONSTAR | LCSC | C84256 | 0.012
12 | 100Ω | R13 | R0805 | 1 | 0805W8F1000T5E | UniOhm | LCSC | C17408 | 0.002
13 | 1K | R11,R12 | 0805 | 2 | 0805W8F1001T5E | UniOhm | LCSC | C17513 | 0.002
14 | 4.7K | R1,R3,R4 | R0805 | 3 | 0805W8F4701T5E | UniOhm | LCSC | C17673 | 0.002
15 | BH1750FVI-TR | U1 | WSOF-6_L2.6-W1.6-P0.50-TL-EP | 1 | BH1750FVI-TR | ROHM | LCSC | C78960 | 0.998
16 | WS2812B-B | LED35,LED36,LED37,LED38,LED39,LED40,LED41,LED42,LED43,LED44,LED45,LED46,LED47,LED48,LED49,LED50,LED51,LED52,LED53,LED54,LED55,LED56,LED57,LED58,LED59,LED60,LED61,LED62,LED63,LED64,LED65,LED66,LED67,LED68,LED69,LED70,LED71,LED72,LED73,LED74,LED75,LED76,LED77,LED78,LED79,LED80,LED81,LED82,LED83,LED84,LED85,LED86,LED87,LED88,LED89,LED90,LED91,LED92,LED93,LED94,LED95,LED96,LED97,LED98,LED99,LED100,LED101,LED102,LED103,LED104,LED105,LED106,LED107,LED108,LED109,LED110,LED111,LED112,LED113,LED114,LED115,LED4,LED5,LED6,LED7,LED17,LED18,LED19,LED20,LED21,LED22,LED23,LED24,LED25,LED26,LED27,LED28,LED29,LED30,LED31,LED32,LED33,LED34,LED3,LED1,LED8,LED9,LED10,LED11,LED12,LED13,LED14,LED15,LED16 | LED-5050_4P | 114 | WS2812B-B | Worldsemi | LCSC | C114586 | 0.094
17 | 50 | R10 | 0805 | 1 | 0805W8F1002T5E | UniOhm | LCSC | C17414 | 0.001
18 | 100uF | C8,C9 | CAP-SMD_L3.5-W2.8 | 2 | TAJB107K006RNJ | AVX | LCSC | C16133 | 0.101
19 | CD4148WP | D1 | D1206-RD | 1 | CD4148WP | LIZ | LCSC | C109000 | 0.014
20 | RP2040 | QU1 | LQFN-56_L7.0-W7.0-P0.4-EP | 1 | RP2040 | Raspberry Pi(树莓派) | LCSC | C2040 | 1.213
21 | W25Q128JWPIQ | QU2 | WSON-8_L6.0-W5.0-P1.27-BL-EP | 1 | W25Q128JWPIQ | WINBOND(华邦) | LCSC | C2689660 | 1.169
22 | 12MHz | QX1 | CRYSTAL-SMD_4P-L3.2-W2.5-BL | 1 | X322512MSB4SI | YXC | LCSC | C9002 | 0.083
23 | AMS1117-3.3 | U2 | SOT-223_L6.5-W3.5-P2.30-LS7.0-BR | 1 | AMS1117-3.3 | AMS | LCSC | C6186 | 0.155
24 | CFV206-60.003KDZF | X1 | OSC-TH_BD2.0-P0.70-D0.3 | 1 | CFV206-60.003KDZF | CITIZEN | LCSC | C389957 | 0.196
25 | BS-6-1 | BT1,BT2 | BAT-SMD_BS-6-1 | 2 | BS-6-1 | Q&J | LCSC | C969909 | 0.221

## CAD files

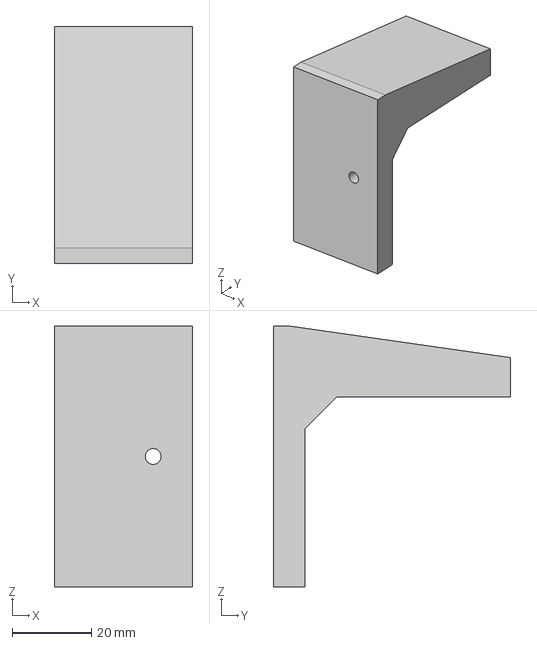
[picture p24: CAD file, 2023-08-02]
src/3d_print/tablestand_v2/standfuss_v2_normal.step
35.0 x 60.0 x 66.0 mm

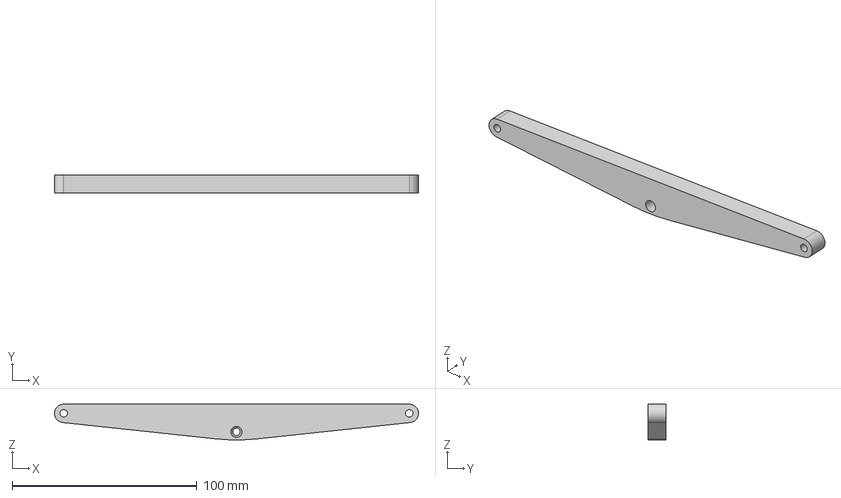
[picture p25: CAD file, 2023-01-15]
src/3d_print/wallmount_v1/wordclock_wallmount.step
197.0 x 10.0 x 19.4 mm

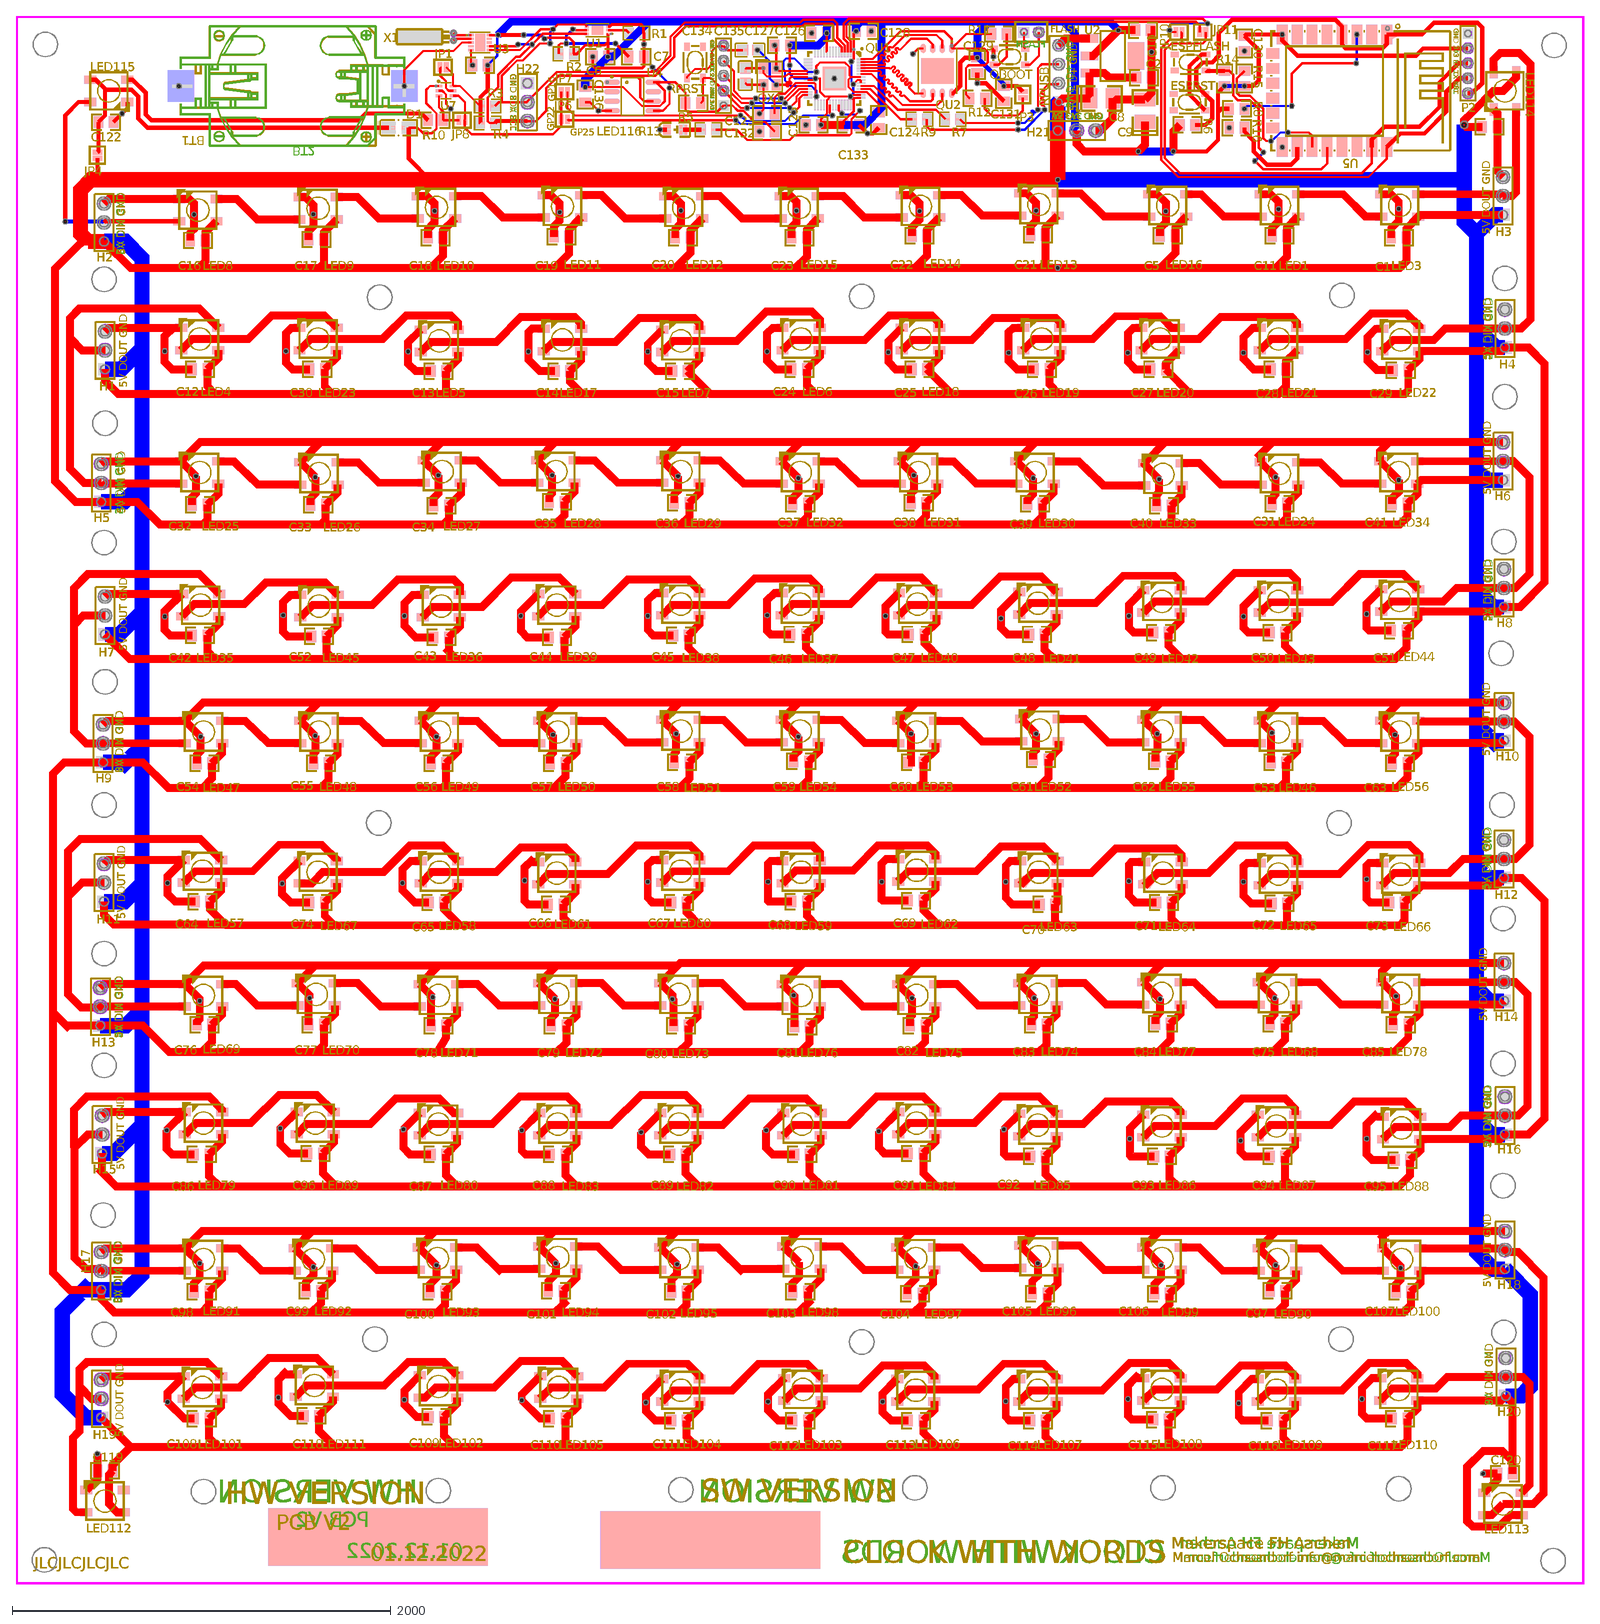
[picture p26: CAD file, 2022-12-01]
src/lasercut/v2/helper/PCB_wordclocksmall_2022-12-01.dxf
GND SDA SCL
GND SWCLK SWD RUN 3V3
5V D- D+ GND
GND 3V3 5V
GND 3v3 RX TX RST
5V DIN GND
CLOCK WITH WORDS
Marcel Ochsendorf info@marcelochsendorf.com
Makerspace FH Aachen
HW VERSION
SW VERSION
01.12.2022
PCB V2
FLASH
5V DOUT GND
GP25
GP16
GP22
JLCJLCJLCJLC
U7
U3
R7
R9
C134
C135
C136
ESPFLASH
JP1
JP8
JP10
JP11
P2
R6
R8
R14
R15
R16
U4
U5
H21
H22
JP4
JP6
JP7
R2
LED116
R13
R11
R12
C131
C132
C133
RPRST
ESPRST
RPUSB
C130
C123
C124
C125
C126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

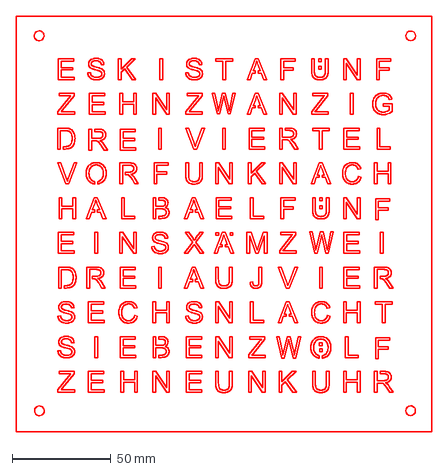
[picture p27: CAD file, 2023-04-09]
src/lasercut/v2/layers_seperated/1_textgerman_layer.dxf
209.9 x 209.8 mm

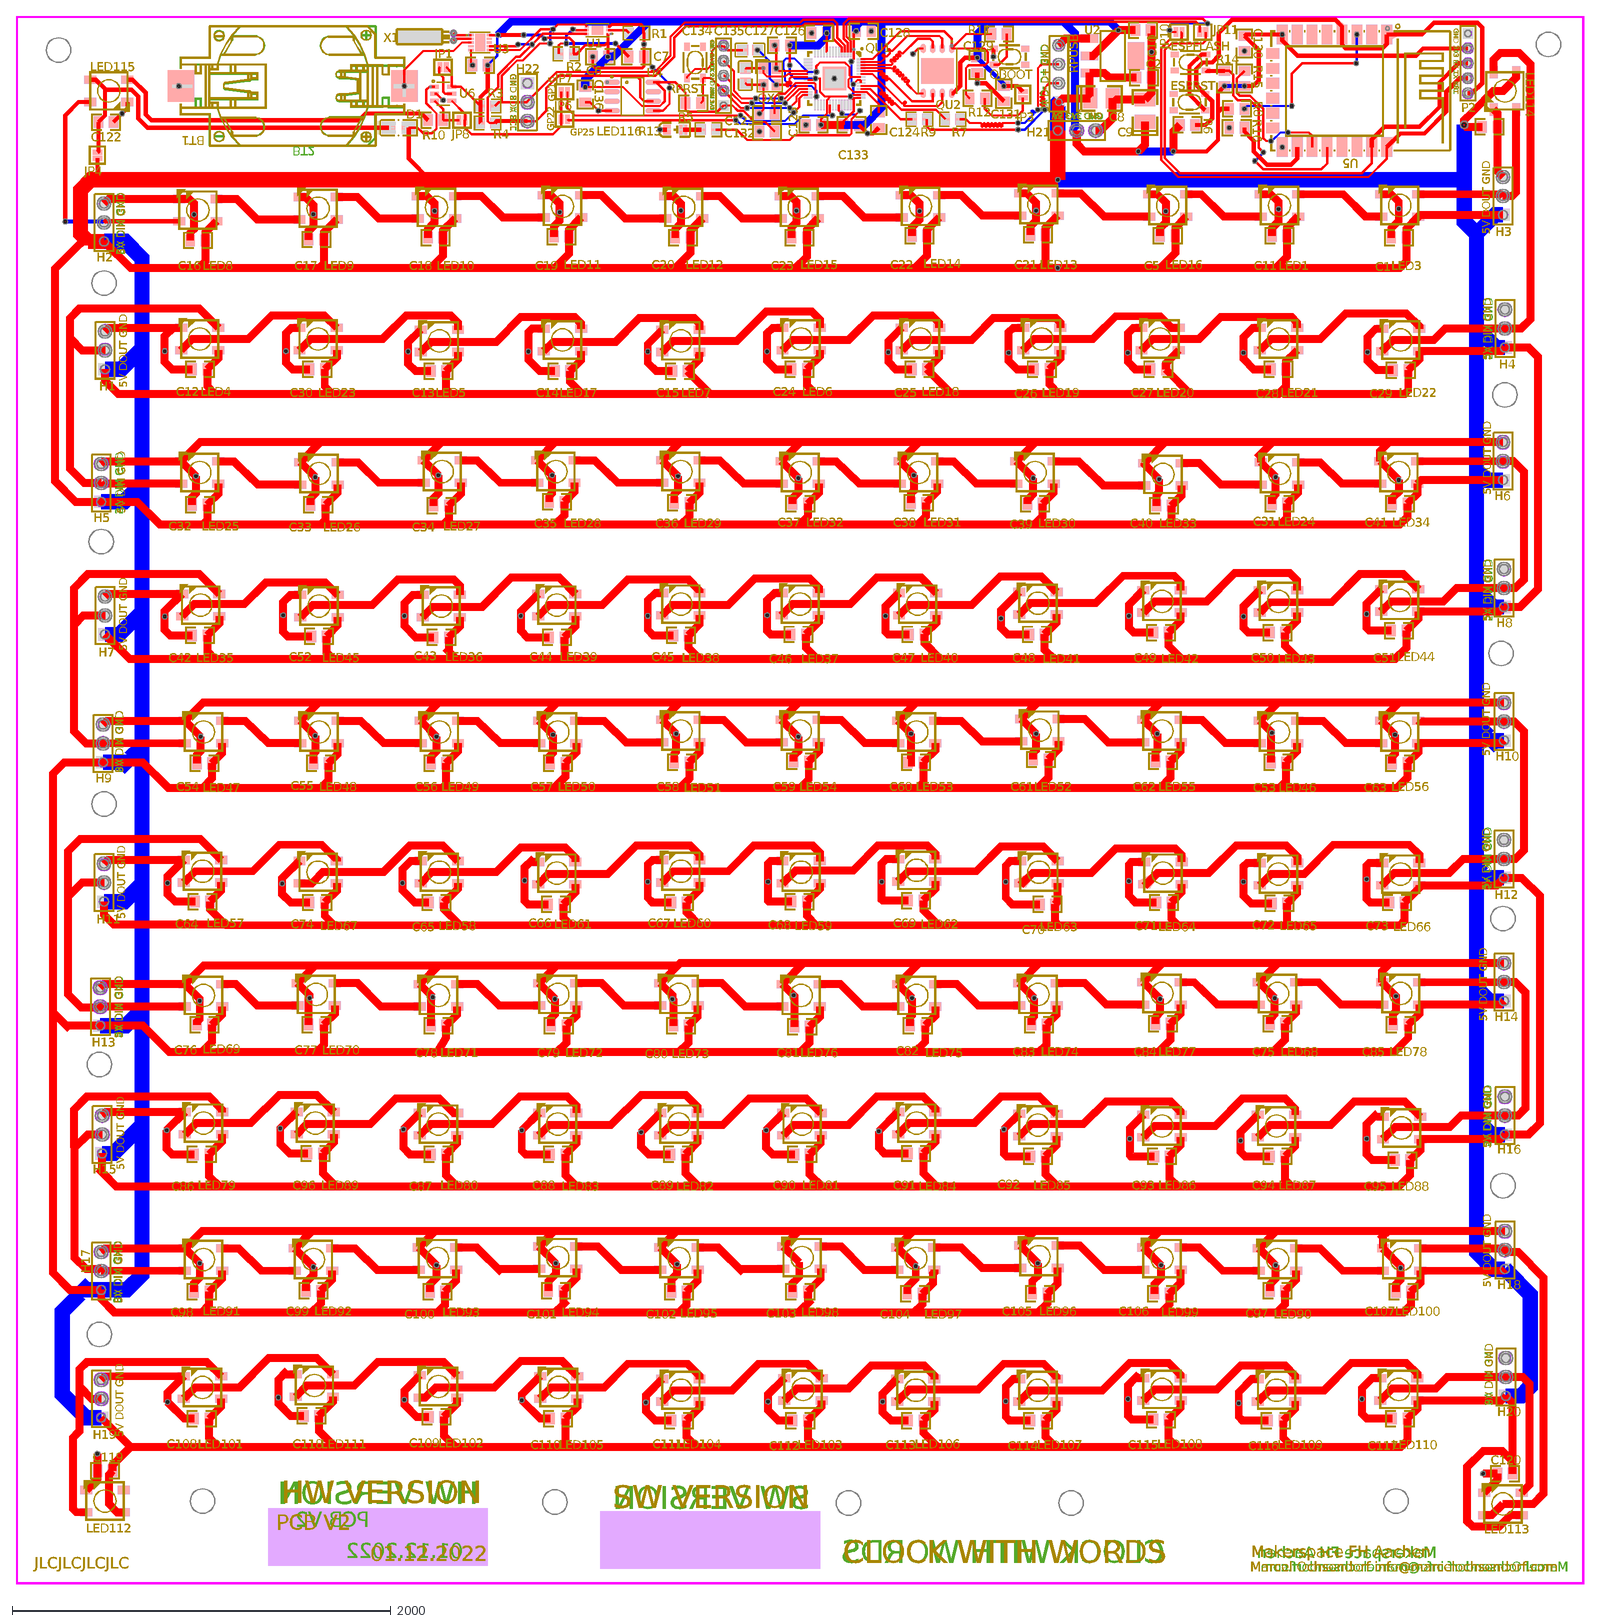
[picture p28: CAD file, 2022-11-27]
src/pcb/v2/PCB_wordclocksmall_2022-11-27.dxf
GND SDA SCL
GND SWCLK SWD RUN 3V3
5V D- D+ GND
GND 3V3 5V
GND 3v3 RX TX RST
5V DIN GND
CLOCK WITH WORDS
Marcel Ochsendorf info@marcelochsendorf.com
Makerspace FH Aachen
HW VERSION
SW VERSION
01.12.2022
PCB V2
5V DOUT GND
GP25
GP16
GP22
JLCJLCJLCJLC
BT2
U3
R7
R9
C134
C135
C136
ESPFLASH
JP1
JP8
JP10
JP11
P2
R6
R8
R14
R15
R16
U4
U5
U6
H21
H22
JP4
JP6
JP7
R2
LED116
R13
R11
R12
C131
C132
C133
RPRST
ESPRST
RPUSB
C130
C123
C124
C125
C126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

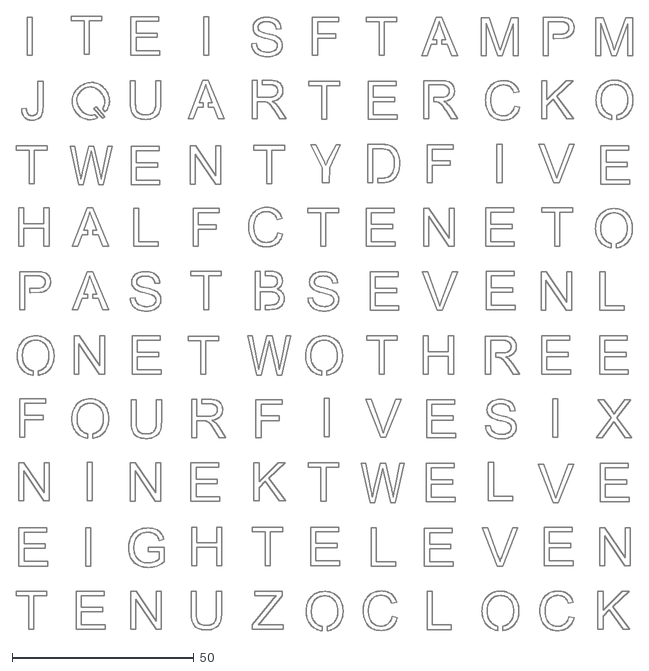
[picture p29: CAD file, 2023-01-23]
src/lasercut/v2/layers_seperated/1_textenglish_am_pm_layer.dxf
169.8 x 169.2

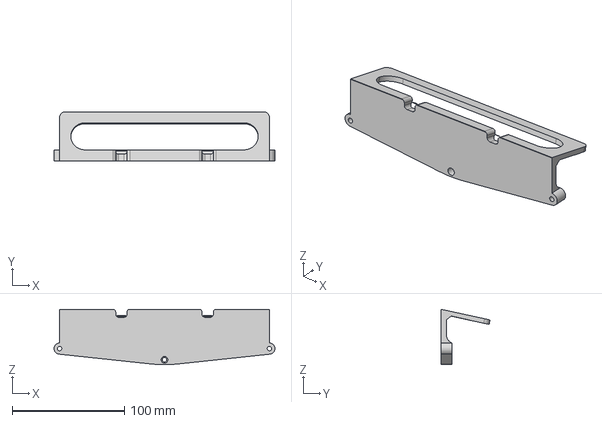
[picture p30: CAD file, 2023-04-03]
src/3d_print/tablestand_v2/wordclock_tablestand_cable_v2.step
197.0 x 43.9 x 49.4 mm

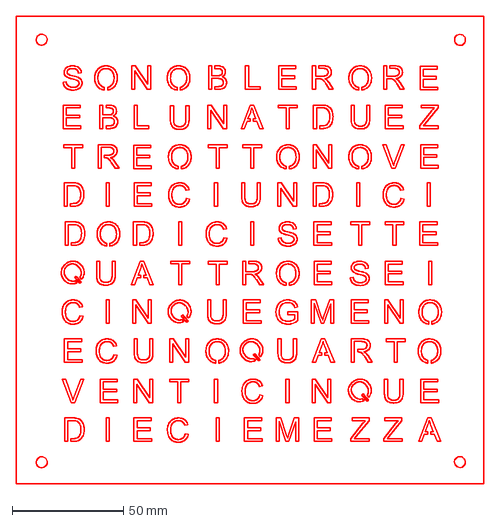
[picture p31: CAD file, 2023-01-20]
src/lasercut/v2/layers_seperated/1_textitalian_layer.dxf
209.9 x 209.8 mm

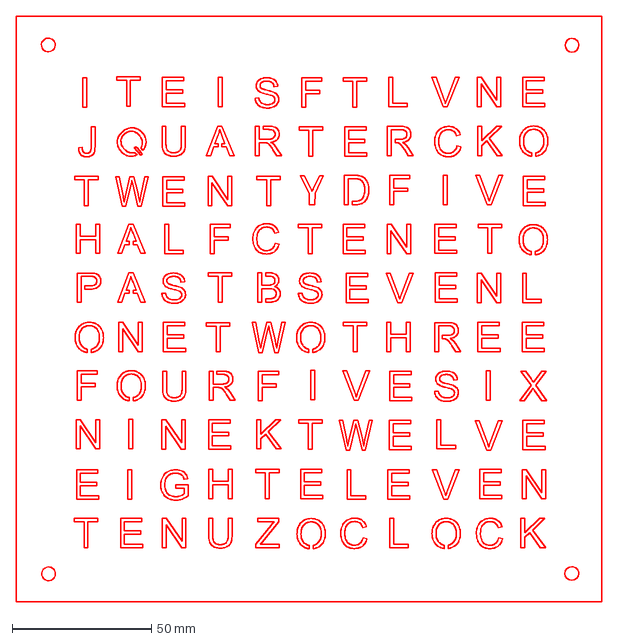
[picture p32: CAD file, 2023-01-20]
src/lasercut/v2/layers_seperated/1_textenglish_layer.dxf
209.9 x 209.8 mm

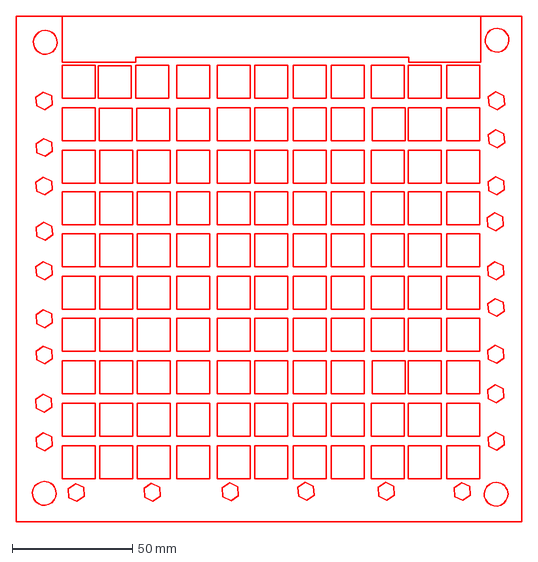
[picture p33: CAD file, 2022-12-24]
src/lasercut/v2/layers_seperated/2_lightguidehexnut_layer.dxf
209.9 x 209.8 mm

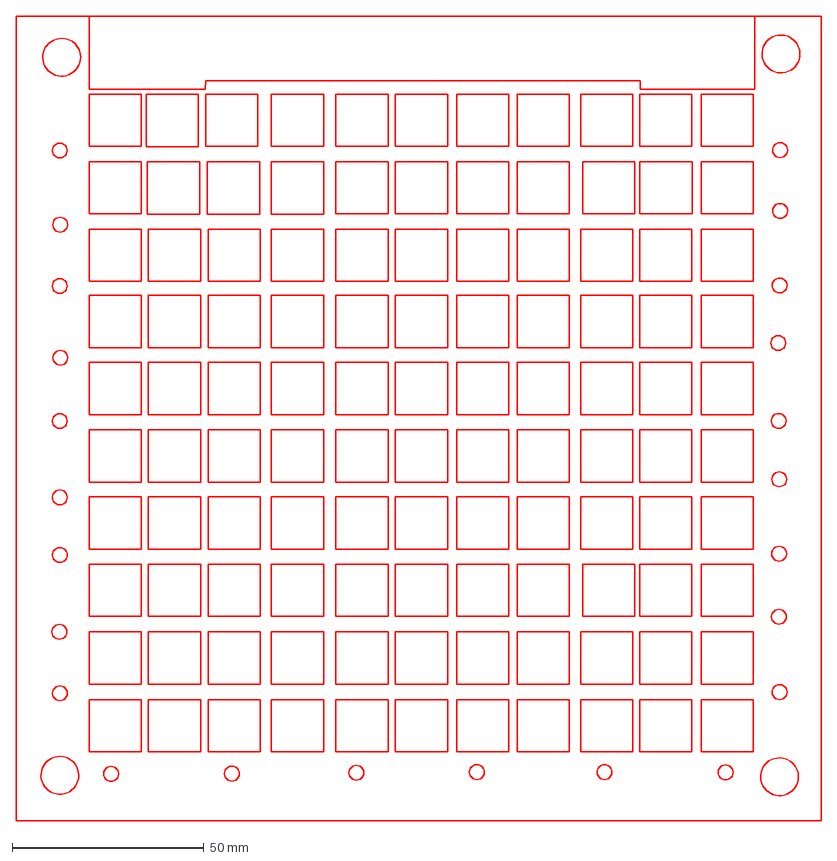
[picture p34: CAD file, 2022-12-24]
src/lasercut/v2/layers_seperated/0_opaque_layer.dxf
209.9 x 209.9 mm

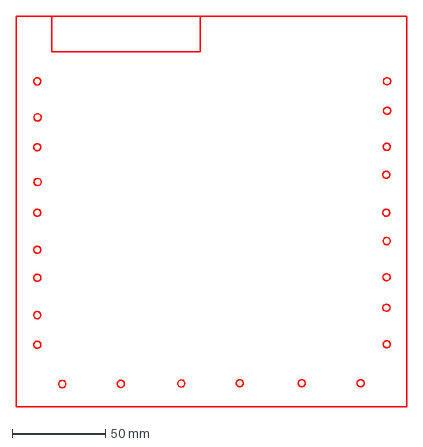
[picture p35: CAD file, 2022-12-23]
src/lasercut/v2/layers_seperated/3_backcover_layer.dxf
209.9 x 209.9 mm

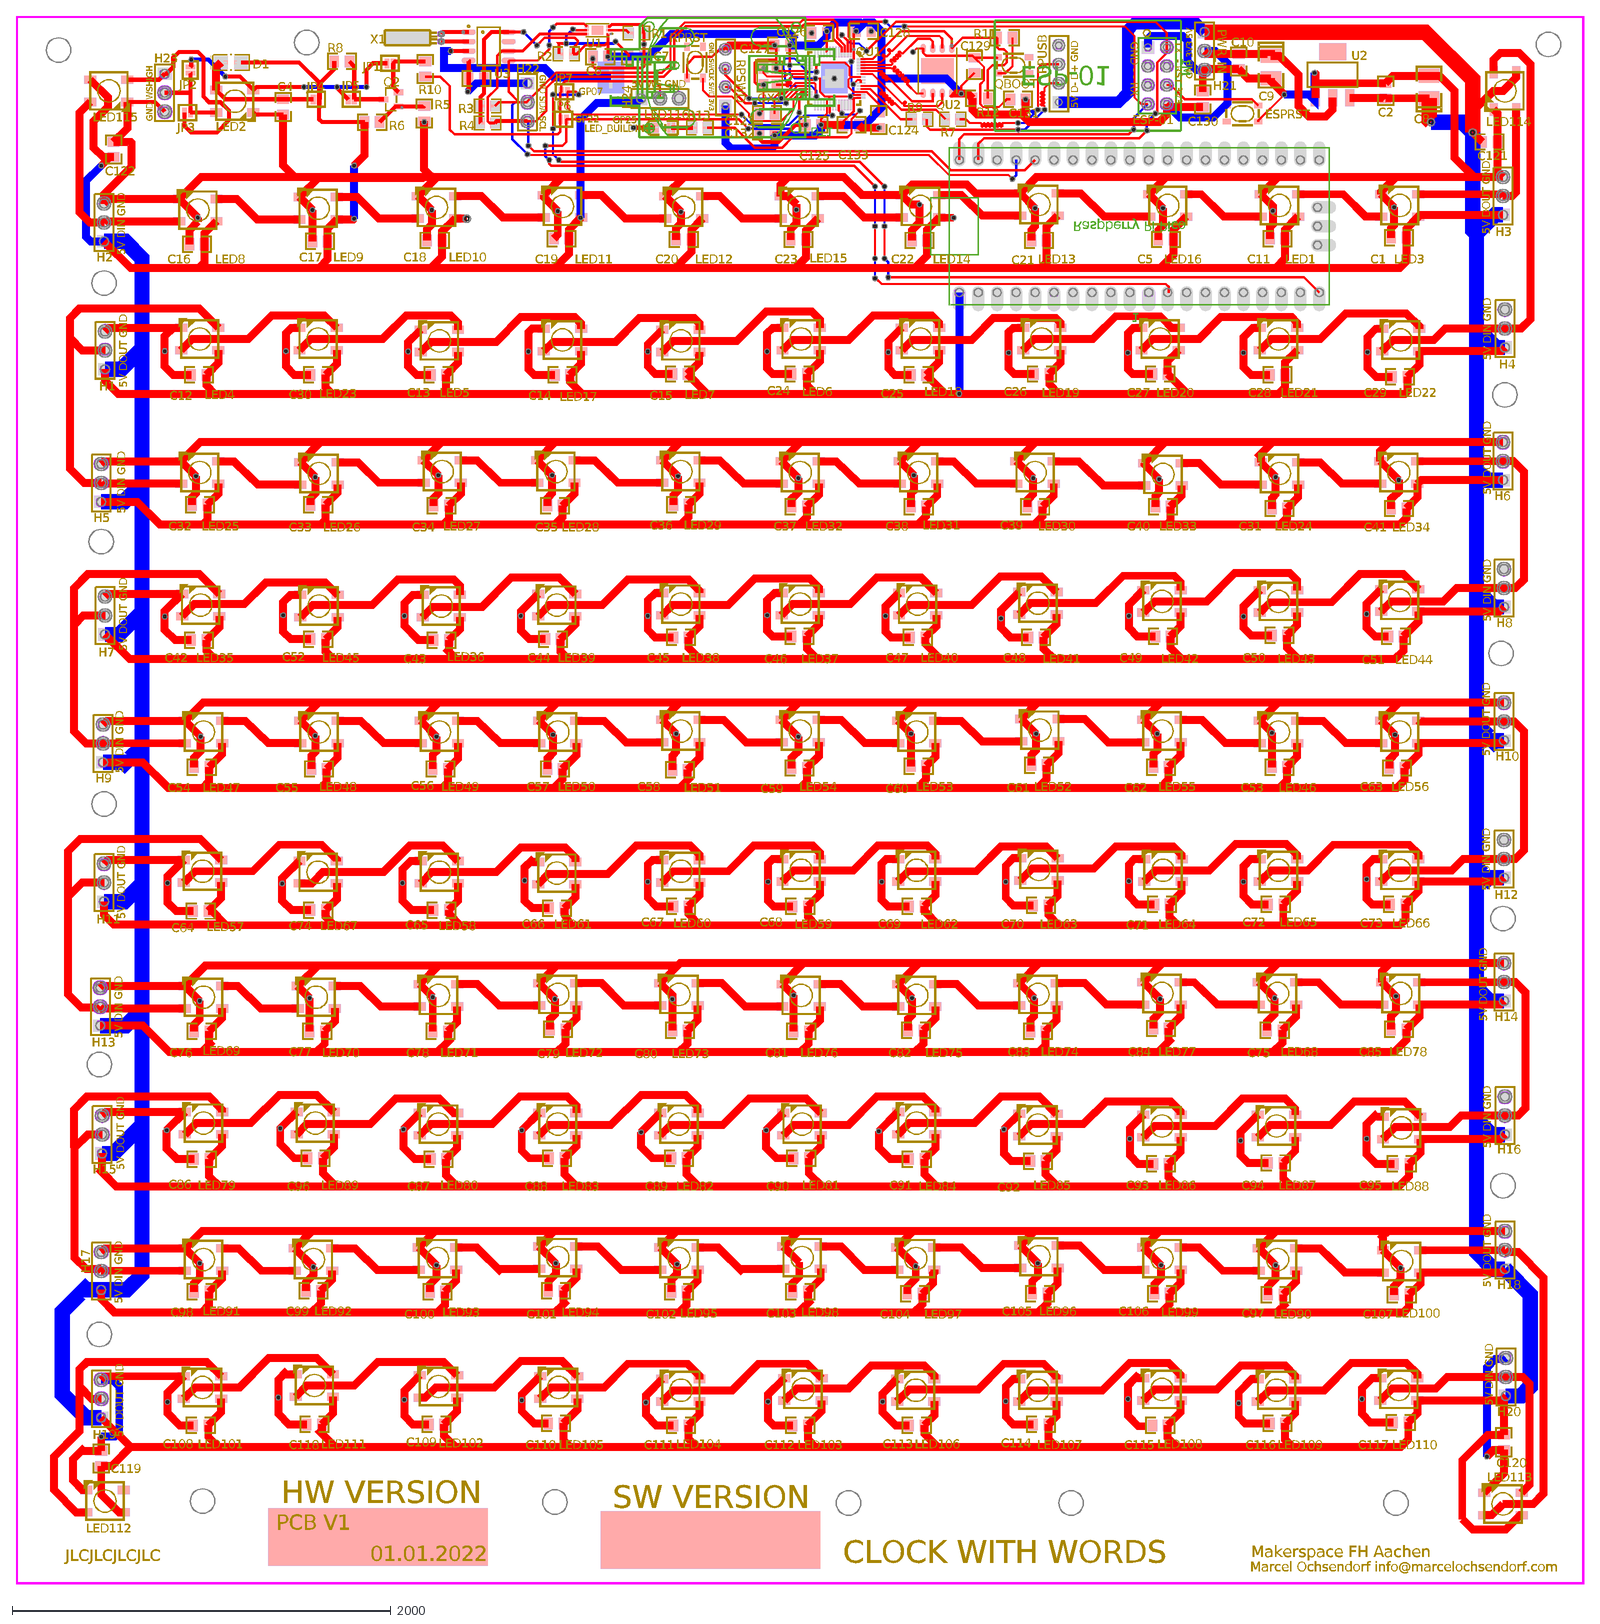
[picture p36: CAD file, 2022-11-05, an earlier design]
src/pcb/v1/PCB_wordclocksmall_2022-11-05.dxf
5V DOUT GND
5V DIN GND
5V D- D+ GND
GND 3V3 5V
PWR_IN
GND - - RX
ESP-01
TX - RST 3V3
LED_BUILDIN
GP25
5V WS GND
GP07
GP22
GND SDA SCL
GND WSHIGH
HW VERSION
SW VERSION
CLOCK WITH WORDS
PCB V1
Marcel Ochsendorf info@marcelochsendorf.com
01.01.2022
Makerspace FH Aachen
JLCJLCJLCJLC
GND SWCLK SWD 3V3
LED116
R13
JP7
R11
R12
JP6
C131
C132
C133
RPRST
ESPRST
RPSWD
RPUSB
R7
R9
H23
H24
C130
C123
C124
C125
C126
C127
C128
C129
C6
C7
R1
R2
U1
H22
H21
C42
C43
C44
C45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

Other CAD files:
src/3d_print/tablestand_v2/standfuss_v2_mirrored.step
src/3d_print/tablestand_v2/standfuss_v2_mirrored.f3d
src/3d_print/tablestand_v2/standfuss_v2_mirrored.stl
src/3d_print/tablestand_v2/standfuss_v2_normal.f3d
src/3d_print/tablestand_v2/standfuss_v2_normal.stl
src/3d_print/tablestand_v2/wordclock_standfuss_v2.f3d
src/3d_print/tablestand_v2/wordclock_tablestand_cable_v2.f3d
src/3d_print/tablestand_v2/wordclock_tablestand_cable_v2.stl
src/3d_print/wallmount_v1/wordclock_wallmount.f3d
src/3d_print/wallmount_v1/wordclock_wallmount.stl

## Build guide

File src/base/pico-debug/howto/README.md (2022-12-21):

## About debugging

This [executive summary](about.md) might be of interest, particularly if you are new to debugging.

## building Pico applications

For applications that use pico-sdk (pico-examples, etc. ... this is true of nearly all code), please follow the instructions in [building.md](building.md).

## debugging Pico applications with pico-debug using the GDB protocol

You have a choice between this and "debugging Pico applications with pico-debug without using the GDB protocol" further below.

First make certain that you have followed the steps above in "building Pico applications".

For OpenOCD users, please follow the instructions in [openocd.md](openocd.md).

For pyOCD users, please follow the instructions in [pyocd.md](pyocd.md).

Then proceed to "debuggers that use GDB" immediately below.

## debuggers that use GDB

First make certain that you have your GDB implementation of choice running (OpenOCD, pyOCD, etc.).

For [Visual Studio Code](https://code.visualstudio.com/) users, then also read [vscode.md](vscode.md).

For [SEGGER Embedded Studio](https://www.segger.com/products/development-tools/embedded-studio/) users, take a look at the pico-ses example in [pico-demos](https://github.com/majbthrd/pico-demos).

## debugging Pico applications with pico-debug without using the GDB protocol

You have a choice between this and "debugging Pico applications with pico-debug using the GDB protocol" further above.

First make certain that you have followed the steps above in "building Pico applications".

If you are a [Rowley Crossworks for ARM](https://www.rowley.co.uk/arm/index.htm) user, v4.8.3 and higher is already capable of debugging RP2040 targets (including ones using pico-debug).

If you use [Keil MDK](https://www.arm.com/products/development-tools/embedded-and-software/keil-mdk) or [Keil MDK-Lite](https://www2.keil.com/mdk5/editions/lite), take a look at [Pico_Template](https://github.com/GorgonMeducer/Pico_Template).

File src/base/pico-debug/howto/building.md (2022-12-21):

## Pico SDK

If your local copy of Pico SDK was downloaded prior to 3 Jun 2021, you will need to reinstall it.  Versions prior to this are incompatible with pico-debug.

Pico SDK is available here: https://github.com/raspberrypi/pico-sdk

## Install the Toolchain

```
$ sudo apt update
$ sudo apt install cmake gcc-arm-none-eabi libnewlib-arm-none-eabi build-essential
```

## Invoking cmake

From the pico directory we created earlier, cd into pico-examples and create a build directory:

```
$ cd ~/pico/pico-examples
$ mkdir build
$ cd build
```

Set PICO_SDK_PATH to point to the previously created pico-sdk directory:

```
$ export PICO_SDK_PATH=../../pico-sdk
```

Invoke cmake to create the files needed for building debug versions of examples:

```
$ cmake -DCMAKE_BUILD_TYPE=Debug ..
Using PICO_SDK_PATH from environment ('../../pico-sdk')
PICO_SDK_PATH is ...
   .
   .
   .
-- Build files have been written to: ...
```

## Building of "picoboard_blinky"

```
$ cd ~/pico/pico-examples/build/picoboard/blinky
$ make -j4
```

At this point, you have picoboard_blinky.uf2 as well as all the files to optionally debug with openocd, gdb, and pico-debug.

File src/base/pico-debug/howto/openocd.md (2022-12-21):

## pre-built openocd

Pre-built openocd binaries compatible with pico-debug [can be found here](https://github.com/earlephilhower/pico-quick-toolchain/releases/) for several operating systems.

## Build openocd yourself (Linux specific)

Users can choose between the authentic OpenOCD or Raspberry Pi's own dated OpenOCD fork which their documentation continues to point to.

Here are the steps to build the authentic OpenOCD:

```
$ sudo apt install automake autoconf build-essential texinfo libtool libhidapi-dev libusb-1.0-0-dev
$ git clone git://git.code.sf.net/p/openocd/code openocd
$ cd openocd
$ ./bootstrap
$ ./configure --enable-cmsis-dap
$ make -j4
$ sudo make install
```

However, users that are beholden to Raspberry Pi (and its proprietary pico-probe) will find that they must continue using the RPi fork, and should freshly download the source code to something no older than 2021 Jun 18 and re-build it to ensure compatibility with pico-debug.

For Mac users building openocd, please also look at [the suggestions here](https://github.com/majbthrd/pico-debug/issues/5).

For OpenBSD users, please also look at [the suggestions here](https://github.com/majbthrd/pico-debug/discussions/23).

## Install GDB

```
$ sudo apt install gdb-multiarch
```

## Use GDB, OpenOCD, and pico-debug to debug 'blinky'

If you have not already built blinky (or whichever app that you might choose to debug), some [sample instructions are here](building.md).

Obtain "pico-debug-gimmecache.uf2" from the Releases at:

https://github.com/majbthrd/pico-debug

Boot the RP2040 with the BOOTSEL button pressed, copy over pico-debug-gimmecache.uf2 to the RP2040, and it immediately reboots as a CMSIS-DAP adapter (ready for OpenOCD to talk to it).

```
$ openocd -f board/pico-debug.cfg
```

Your output should look something like this:

```
Info : Hardware thread awareness created
Info : RP2040 Flash Bank Command
Info : Listening on port 6666 for tcl connections
Info : Listening on port 4444 for telnet connections
Info : CMSIS-DAP: SWD  Supported
Info : CMSIS-DAP: FW Version = 2.0.0
Info : CMSIS-DAP: Interface Initialised (SWD)
Info : SWCLK/TCK = 0 SWDIO/TMS = 0 TDI = 0 TDO = 0 nTRST = 0 nRESET = 0
Info : CMSIS-DAP: Interface ready
Info : clock speed 4000 kHz
Info : SWD DPIDR 0x0bc12477
Info : SWD DLPIDR 0x00000001
Info : rp2040.core0: hardware has 4 breakpoints, 2 watchpoints
Info : starting gdb server for rp2040.core0 on 3333
Info : Listening on port 3333 for gdb connections
```

This OpenOCD terminal needs to be left open. So go ahead and open another terminal; in this one we’ll attach a gdb instance to OpenOCD:

```
$ cd ~/pico/pico-examples/build/picoboard/blinky
$ gdb-multiarch picoboard_blinky.elf
```

Connect GDB to OpenOCD:

```
(gdb) target remote localhost:3333
```

and load picoboard_blinky.elf into flash:

```
(gdb) load
Loading section .boot2, size 0x100 lma 0x10000000
Loading section .text, size 0x4828 lma 0x10000100
Loading section .rodata, size 0xd6c lma 0x10004928
Loading section .binary_info, size 0x1c lma 0x10005694
Loading section .data, size 0xa4c lma 0x100056b0
Start address 0x100001e8, load size 24828
Transfer rate: 8 KB/sec, 4138 bytes/write.
```

and then start it running:

```
(gdb) monitor reset init
(gdb) continue
```

Or, if you want to set a breakpoint at main() before running the executable:

```
(gdb) monitor reset init
(gdb) b main
(gdb) continue
Continuing.
Note: automatically using hardware breakpoints for read-only addresses.

Breakpoint 1, main () at ../main.c:48
48	  sys_init();
```

before continuing after you have hit the breakpoint:

```
(gdb) continue
```

if the target is running, it can be interrupted with Ctrl-C, at which point another gdb prompt should appear:

```
(gdb)
```

To quit from gdb, type:

```
(gdb) quit
```

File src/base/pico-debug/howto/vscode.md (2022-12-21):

## pico-debug debugging with Visual Studio Code

There are a few [Visual Studio Code](https://code.visualstudio.com/) (aka VS Code) examples online for the RP2040 so far.  So far, they all assume picoprobe.

If you are already set on following one of these, adopt the changes below.  If you are starting fresh, [please try these instructions](vscode1.md).

## adapting existing instructions to switch from picoprobe to pico-debug

To adapt instructions from picoprobe to pico-debug, first make sure that you followed the earlier build steps and have downloaded and installed the newer pico-sdk and openocd in the howto instructions.  This is important.  The newer pico-sdk is needed to fix problems pico-sdk has with single device debugging, and the newer openocd is needed to support single device debugging.

For existing Visual Studio Code examples written for picoprobe, in the launch.js file, replace this picoprobe configuration:

```
             "configFiles": [
                 "/interface/picoprobe.cfg",
                 "/target/rp2040.cfg"
             ],
```

with

```
             "configFiles": [
                 "interface/cmsis-dap.cfg",
                 "target/rp2040-core0.cfg"
             ],
             "openOCDLaunchCommands": [
                 "transport select swd",
                 "adapter speed 4000"
             ],
```

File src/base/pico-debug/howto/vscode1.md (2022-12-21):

## one way to use Visual Studio Code with pico-debug

Before following the steps below, follow [these pico-sdk and pico-examples instructions](building.md).  This gives you all the build tools that are known compatible with pico-debug.

Download and install [Visual Studio Code](https://code.visualstudio.com/).

Run Visual Studio Code, and select the pull-down menu View -> Extensions (or click the Tetris block looking icon on the far left).  Search for and click "Install" for these modules:

```
C/C++ Extension Pack (by Microsoft)
Cortex-Debug (by marus25)
CMake Tools (by Microsoft)
```

For the (pico-examples) project that you want to build, add a .vscode subdirectory.  So, for the picoboard blinky example in pico-examples:

```
mkdir ~/pico/pico-examples/build/picoboard/blinky/.vscode
```

Create a text file named launch.json in the newly-created directory, and paste in the following text:

```
{
     "version": "0.2.0",
     "configurations": [
         {   "name": "Pico Debug",
             "device": "RP2040",
             "gdbPath": "arm-none-eabi-gdb",
             "cwd": "${workspaceRoot}",
             "executable": "${workspaceRoot}/picoboard_blinky.elf",
             "request": "launch",
             "type": "cortex-debug",
             "servertype": "openocd",
             "configFiles": [
                 "interface/cmsis-dap.cfg",
                 "target/rp2040-core0.cfg"
             ],
             "openOCDLaunchCommands": [
                 "transport select swd",
                 "adapter speed 4000"
             ],
             "svdFile": "${env:PICO_SDK_PATH}/src/rp2040/hardware_regs/rp2040.svd",
             "runToMain": true,
             "postRestartCommands": [
                 "break main",
                 "continue"
             ]
         }
     ]
 }
```

IMPORTANT: for the "executable" setting, you will need to customize "picoboard_blinky.elf" to suit the filenames of the project.

In Visual Studio Code, select the pull-down menu File -> Open Folder and choose the project folder than you are working on.  For the picoboard blinky example, that would be navigating to ~/pico/pico-examples/build/picoboard/blinky and clicking the OK button.

At this point, Visual Studio Code shows an easy to miss drop-down box at the top of the window to select a kit (that will disappear if you don’t immediately select something).  If you miss it (which seems easy to do), repeat the File -> Open Folder step above.  The "kit" that you need to select is "GCC for arm-none-eabi", which indicates the compiler used to compile the RP2040 Pico code.

You can confirm the correct compiler has been selected by looking at the blue ribbon at the bottom of the window and looking for a wrench/spanner icon.  The text to the right of the wrench/spanner should say "GCC for arm-none-eabi" followed by a version number.

If you haven’t already done so, boot the Pico with the BOOTSEL button pressed, and copy over to the RP2040 the [pico-debug-gimmecache.uf2](https://github.com/majbthrd/pico-debug) file.

In Visual Studio Code, select the pull-down menu Run -> Start Debugging (or click the play button with a bug on the far left).

At this point, the ribbon at the bottom of the window turns orange and program execution at main() should be ready to begin.  You are debugging at this point!

pico-debug should keep running until you unplug the Pico, so you should be free to debug your code, make changes, recompile, and then run Visual Studio Code again to debug without needing to reload the pico-debug-gimmecache.uf2 file.

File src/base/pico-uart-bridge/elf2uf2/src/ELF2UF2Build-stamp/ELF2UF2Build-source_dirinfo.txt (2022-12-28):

# This is a generated file and its contents are an internal implementation detail.
# The download step will be re-executed if anything in this file changes.
# No other meaning or use of this file is supported.

method=source_dir
command=
source_dir=/Users/marcelochsendorf/Downloads/WordClock/src/base/pico-sdk/tools/elf2uf2
work_dir=

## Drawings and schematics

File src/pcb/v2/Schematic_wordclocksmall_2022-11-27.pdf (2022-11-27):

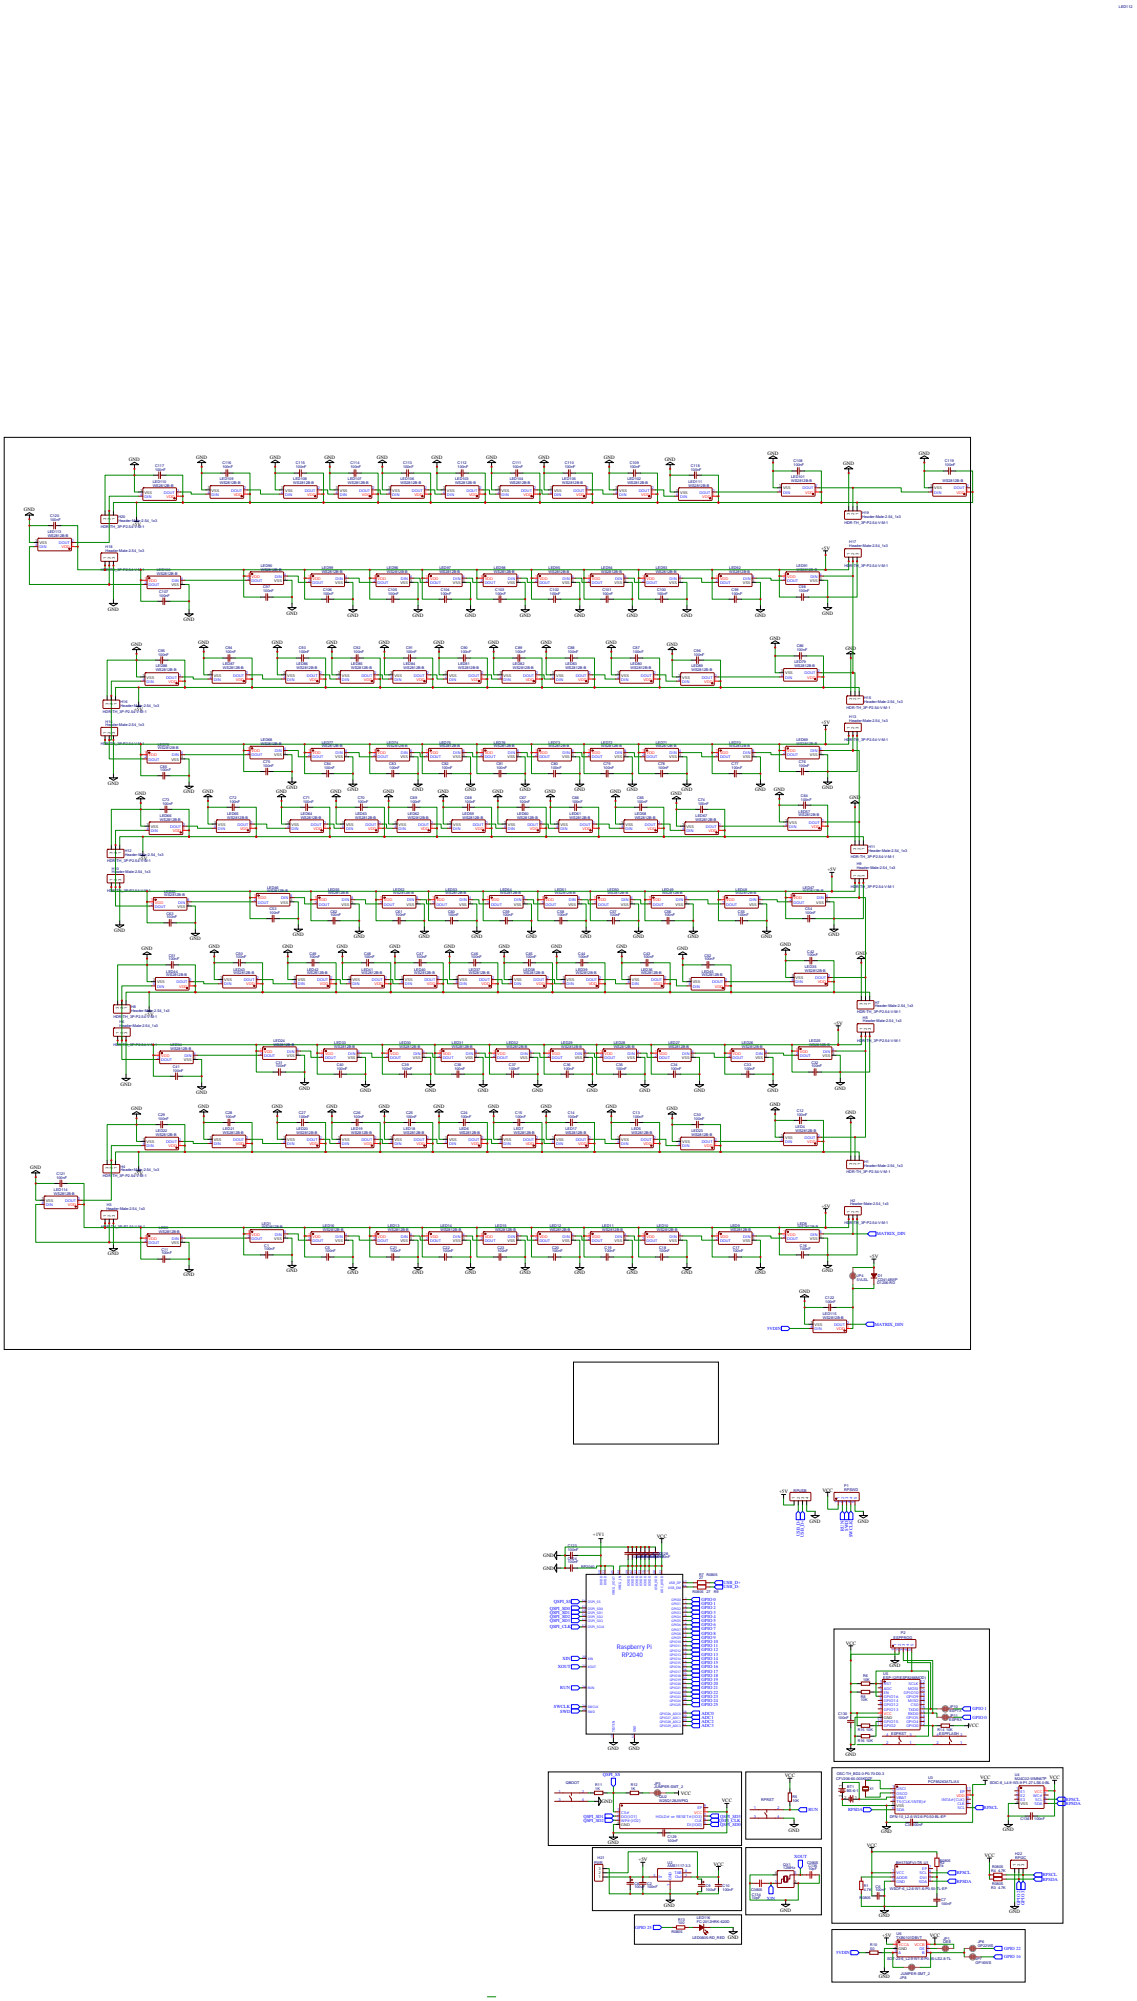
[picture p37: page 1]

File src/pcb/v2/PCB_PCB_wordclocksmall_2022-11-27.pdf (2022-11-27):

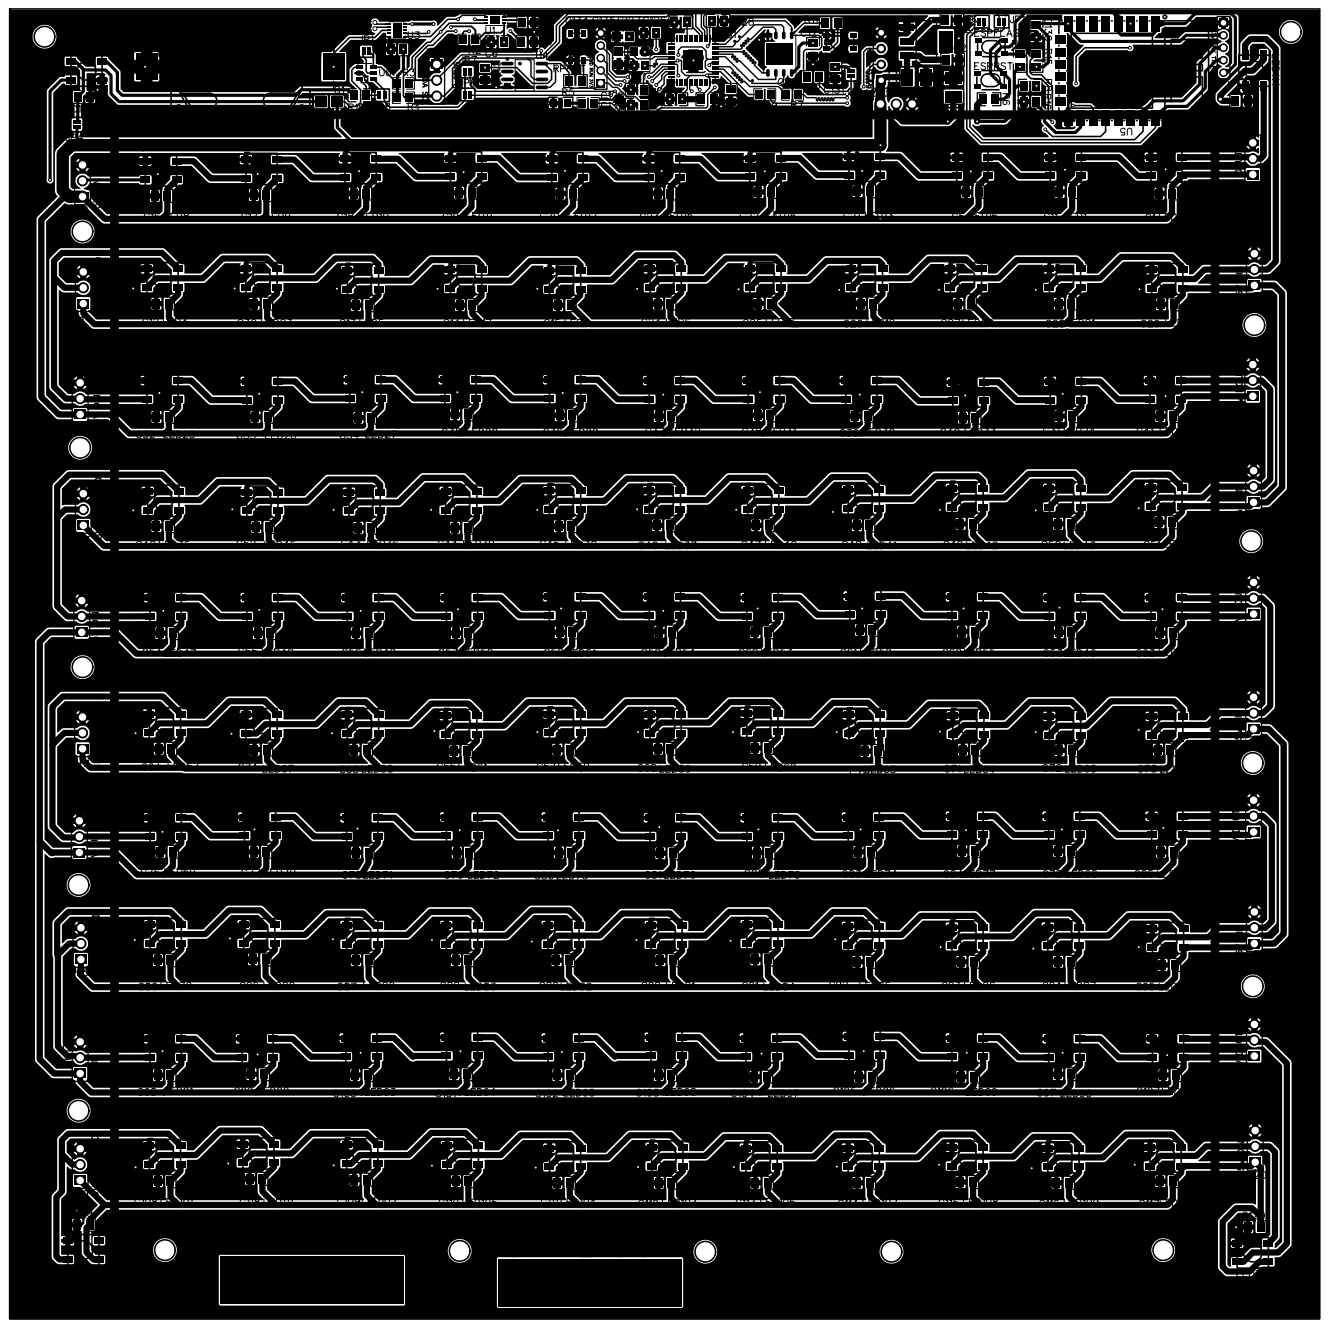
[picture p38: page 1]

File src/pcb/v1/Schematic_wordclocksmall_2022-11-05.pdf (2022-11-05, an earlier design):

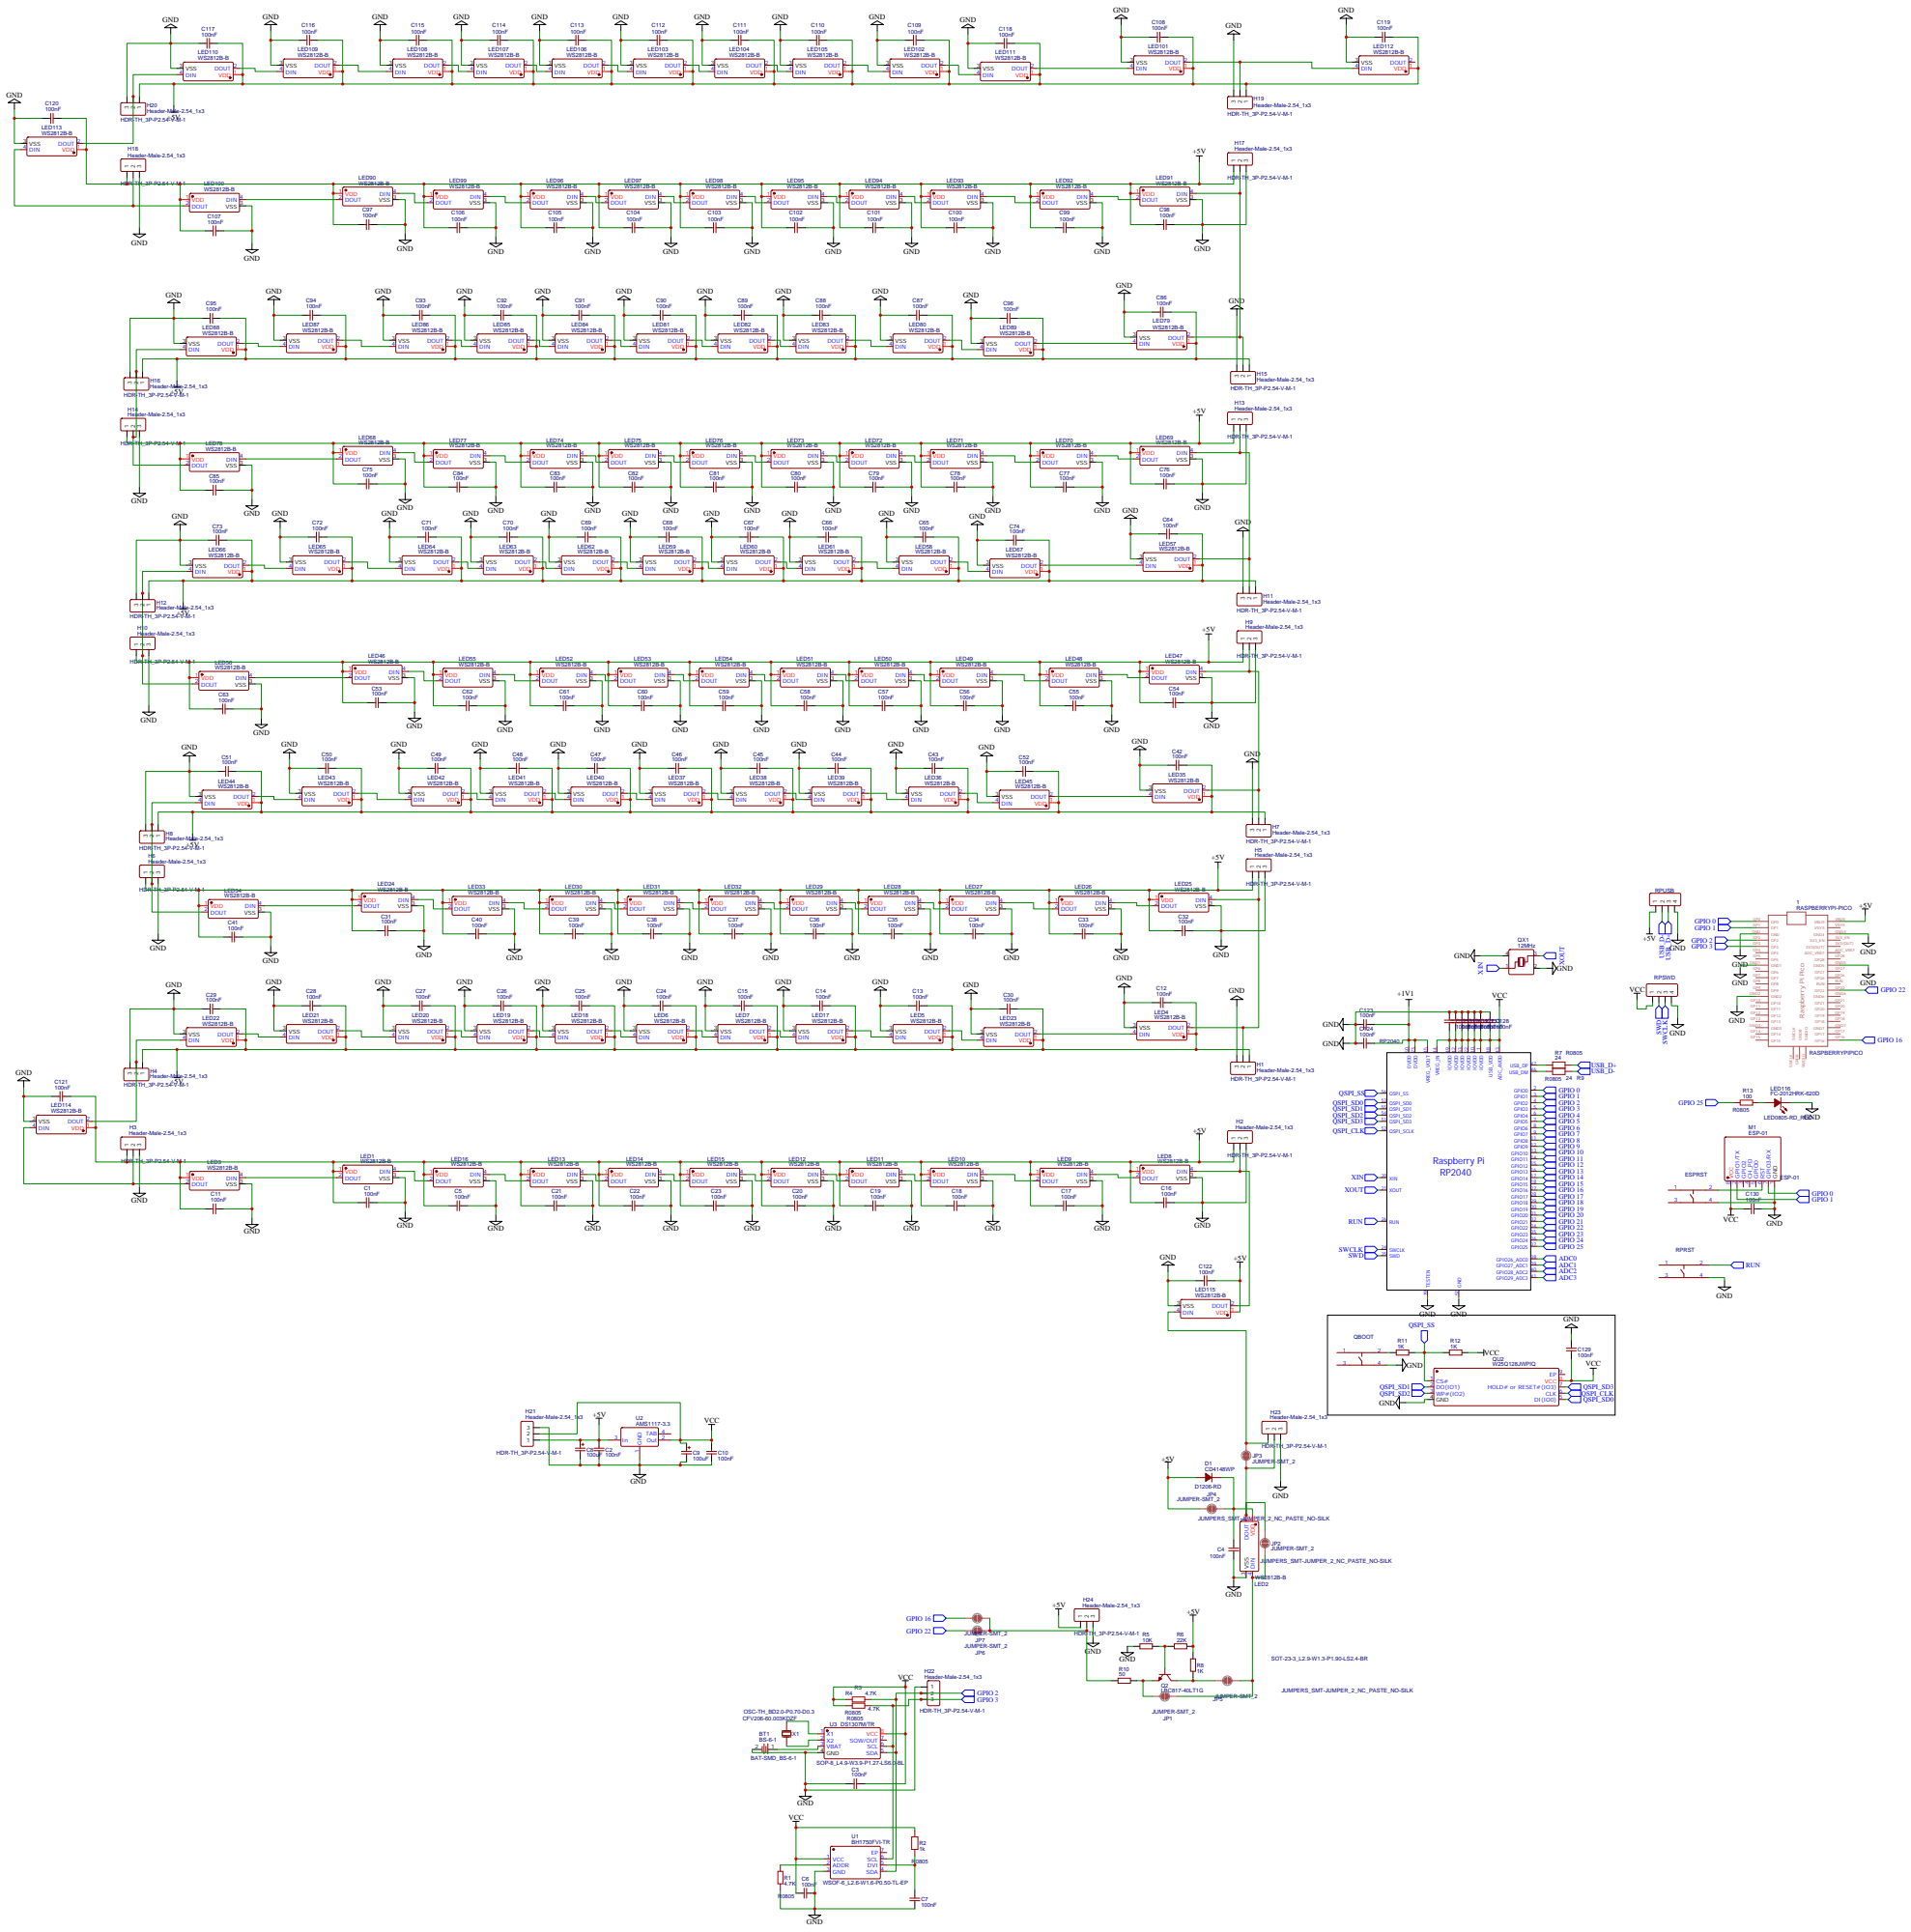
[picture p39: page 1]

SWDIO Raspberry Pi Pico

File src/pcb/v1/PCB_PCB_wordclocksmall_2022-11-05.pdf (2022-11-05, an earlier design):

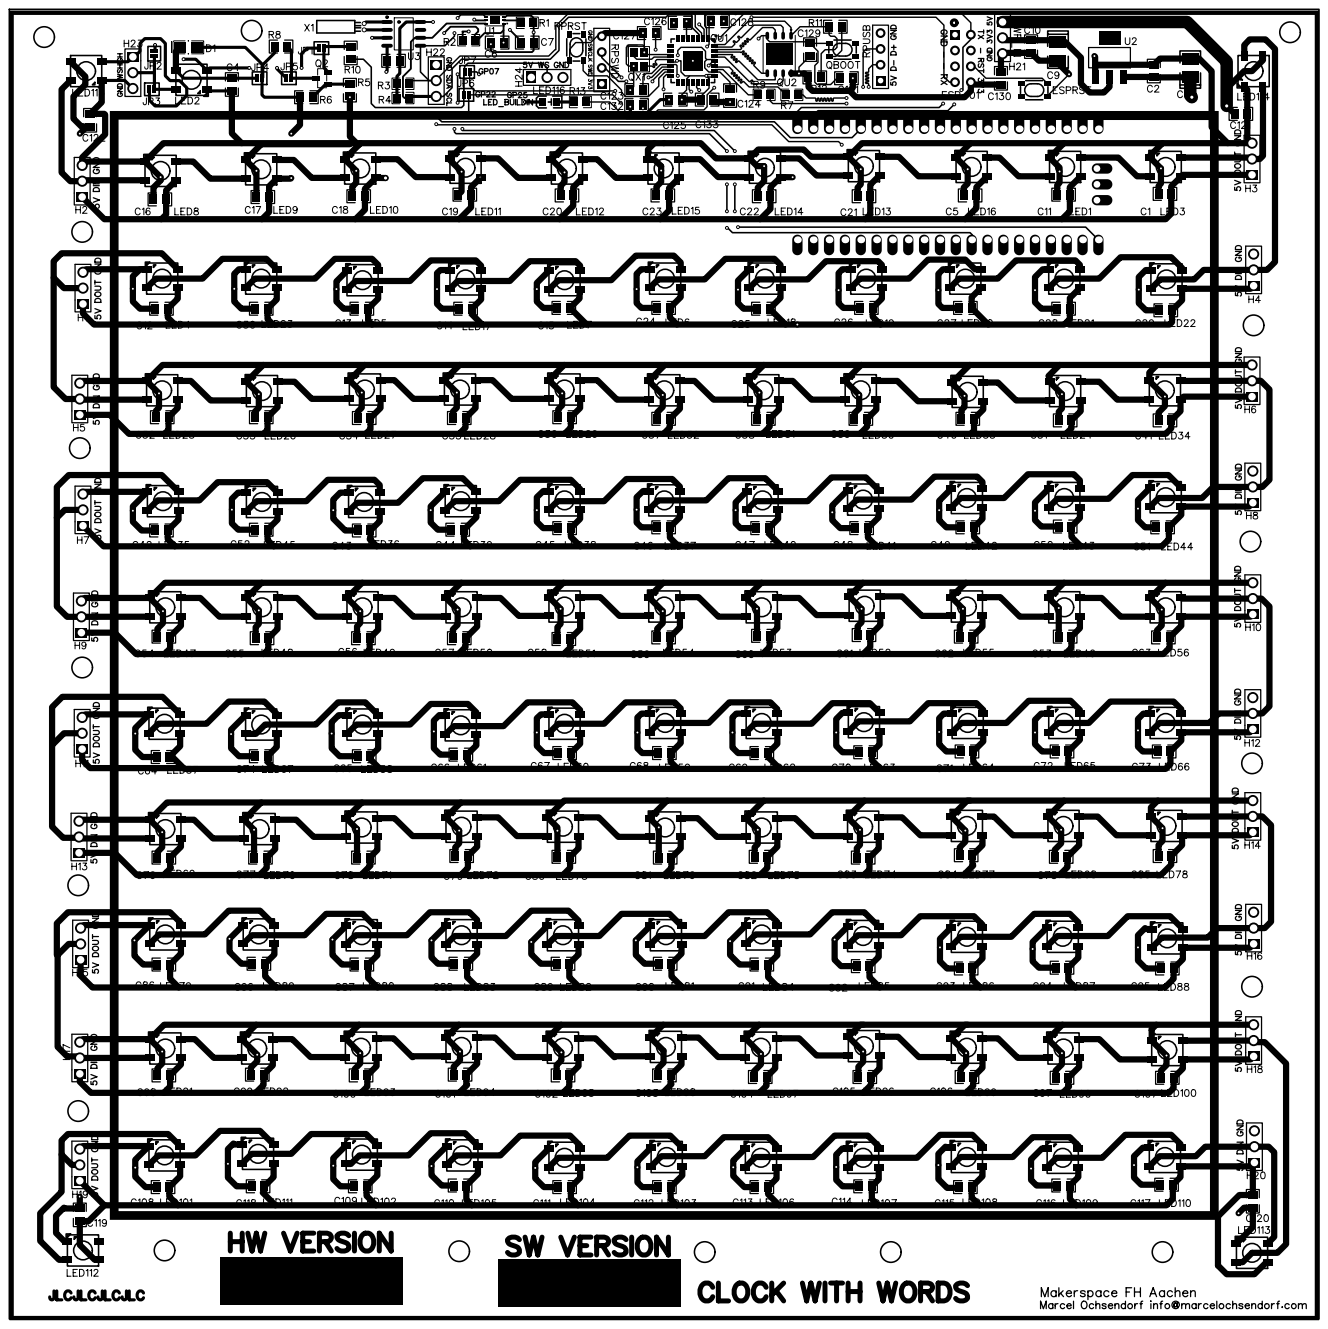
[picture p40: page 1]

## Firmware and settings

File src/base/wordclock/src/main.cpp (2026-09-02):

#include "main.h"

int current_brightness = 10;
int current_brightness_mode = 0; // 0=auto >0-255 = manual
int last_brightness = 0;
int last_tmin = -1;
int last_tsec = -1;
long long last_update = 0;
bool display_update = true;
int brighness_curve = 10;
std::string display_to_ip = ""; // IF THERE IS SET ANYTHING THIS WILL BE SHOWN ON THE CLOCK
bool ignore_wifi_time = false;
int timezone_offset_minutes = 0;
int wifi_time_date_adjustment = 0;

namespace
{
constexpr int TIMEZONE_MINUTES_MIN = -12 * 60;
constexpr int TIMEZONE_MINUTES_MAX = 14 * 60;
constexpr int TIMEZONE_MINUTES_STEP = 15;
constexpr int TIMEZONE_STORAGE_BIAS = 49;
constexpr int TIMEZONE_STORAGE_MAX = (TIMEZONE_MINUTES_MAX / TIMEZONE_MINUTES_STEP) + TIMEZONE_STORAGE_BIAS;

uint8_t encode_timezone_offset(const int _offset_minutes)
{
    return (uint8_t)((_offset_minutes / TIMEZONE_MINUTES_STEP) + TIMEZONE_STORAGE_BIAS);
}

int decode_timezone_offset(const uint8_t _stored_value)
{
    // Zero and erased flash (0xff) both decode to UTC for backward compatibility.
    if (_stored_value < 1 || _stored_value > TIMEZONE_STORAGE_MAX)
    {
        return 0;
    }
    return ((int)_stored_value - TIMEZONE_STORAGE_BIAS) * TIMEZONE_MINUTES_STEP;
}

bool parse_unsigned_value(const std::string &_value, const int _minimum, const int _maximum, int &_result)
{
    if (_value.empty())
    {
        return false;
    }

    int result = 0;
    for (const char ch : _value)
    {
        if (ch < '0' || ch > '9')
        {
            return false;
        }
        const int digit = ch - '0';
        if (digit > _maximum || result > (_maximum - digit) / 10)
        {
            return false;
        }
        result = (result * 10) + digit;
    }

    if (result < _minimum)
    {
        return false;
    }
    _result = result;
    return true;
}

bool extract_time(const std::string &_payload, int &_hour, int &_minute, int &_second)
{
    const size_t first_separator = _payload.find(':');
    const size_t second_separator = first_separator == std::string::npos
                                        ? std::string::npos
                                        : _payload.find(':', first_separator + 1);
    if (first_separator == std::string::npos ||
        second_separator == std::string::npos ||
        _payload.find(':', second_separator + 1) != std::string::npos)
    {
        return false;
    }

    return parse_unsigned_value(_payload.substr(0, first_separator), 0, 23, _hour) &&
           parse_unsigned_value(_payload.substr(first_separator + 1, second_separator - first_separator - 1), 0, 59, _minute) &&
           parse_unsigned_value(_payload.substr(second_separator + 1), 0, 59, _second);
}

bool extract_date(const std::string &_payload, int &_day, int &_month, int &_year)
{
    const size_t first_separator = _payload.find('.');
    const size_t second_separator = first_separator == std::string::npos
                                        ? std::string::npos
                                        : _payload.find('.', first_separator + 1);
    if (first_separator == std::string::npos ||
        second_separator == std::string::npos ||
        _payload.find('.', second_separator + 1) != std::string::npos)
    {
        return false;
    }

    return parse_unsigned_value(_payload.substr(0, first_separator), 1, 31, _day) &&
           parse_unsigned_value(_payload.substr(first_separator + 1, second_separator - first_separator - 1), 1, 12, _month) &&
           parse_unsigned_value(_payload.substr(second_separator + 1), 2000, 2099, _year);
}

int days_in_month(const int _month, const int _year)
{
    static const int days[] = {31, 28, 31, 30, 31, 30, 31, 31, 30, 31, 30, 31};
    if (_month == 2 && RTC_LEAP_YEAR(_year))
    {
        return 29;
    }
    return days[_month - 1];
}

void adjust_date(int &_day, int &_month, int &_year, const int _day_adjustment)
{
    _day += _day_adjustment;
    if (_day < 1)
    {
        _month--;
        if (_month < 1)
        {
            _month = 12;
            _year--;
        }
        _day = days_in_month(_month, _year);
    }
    else if (_day > days_in_month(_month, _year))
    {
        _day = 1;
        _month++;
        if (_month > 12)
        {
            _month = 1;
            _year++;
        }
    }
}
} // namespace

// CLASS INSTANCES
wordclock_faceplate *faceplate = new wordclock_faceplate();
ambient_light *lightsensor = nullptr;
rtc *timekeeper = nullptr;
settings_storage *settings = nullptr;

void switch_fp(wordclock_faceplate *&_instance, wordclock_faceplate::FACEPLATES _faceplate)
{

    if (_instance)
    {
        delete _instance;
    }
    wordclock_faceplate::config.current_faceplate = _faceplate;
    switch (_faceplate)
    {
    case wordclock_faceplate::FACEPLATES::TEST:
        _instance = new wordclock_faceplate();
        break;
    case wordclock_faceplate::FACEPLATES::GERMAN:
        _instance = new wordclock_faceplate_german();
        break;
    case wordclock_faceplate::FACEPLATES::BINARY:
        _instance = new wordclock_faceplate_binary();
        break;
    case wordclock_faceplate::FACEPLATES::ENGLISH:
        _instance = new wordclock_faceplate_english();
        break;
    case wordclock_faceplate::FACEPLATES::ITALIAN:
        _instance = new wordclock_faceplate_italian();
        break;
    case wordclock_faceplate::FACEPLATES::DOTS:
        _instance = new wordclock_faceplate_dots();
        break;
    default:
        _instance = new wordclock_faceplate();
        wordclock_faceplate::config.current_faceplate = wordclock_faceplate::FACEPLATES::TEST;
        break;
    }
}

void init_bh1750(const int _i2_addr)
{
    if (_i2_addr < 0)
    {
        printf("init_bh1750 failed");
        return;
    }

#ifdef USE_BH1750_IF_PRESENT
    if (lightsensor)
    {
        delete lightsensor;
    }
    lightsensor = new ambient_light_bh1750();
#endif
}

void init_eeprom_i2c(const int _i2_addr)
{
    if (_i2_addr < 0)
    {
        printf("init_m24c02 failed");
        return;
    }

#ifdef USE_EEPROM_IF_PRESENT
    if (settings)
    {
        delete settings;
    }
    settings = new settings_storage_eeprom();
#endif
}

void init_rtc_i2c(const int _i2_addr)
{
    if (_i2_addr < 0)
    {
        printf("init_pcf85263 failed");
        return;
    }
#ifdef USE_I2CRTC_IF_PRESENT
    if (timekeeper)
    {
        delete timekeeper;
    }
    timekeeper = new rtc_i2c();
#endif
}

void init_i2c()
{
    i2c_init(i2c_default, PICO_DEFAULT_I2C_SPEED); // 100khz
    gpio_set_function(PICO_DEFAULT_I2C_SDA_PIN, GPIO_FUNC_I2C);
    gpio_set_function(PICO_DEFAULT_I2C_SCL_PIN, GPIO_FUNC_I2C);
    gpio_pull_up(PICO_DEFAULT_I2C_SDA_PIN);
    gpio_pull_up(PICO_DEFAULT_I2C_SCL_PIN);

    for (int addr = 0; addr < (1 << 7); ++addr)
    {
        int ret;
        uint8_t rxdata;
        if ((addr & 0x78) == 0 || (addr & 0x78) == 0x78)
        {
            ret = PICO_ERROR_GENERIC;
        }
        else
        {
            ret = i2c_read_blocking(i2c_default, addr, &rxdata, 1, false);
        }

        if (ret > 0)
        {
            printf("i2c device at %02x \n", addr);
        }

        // CHECK FOR REQUESTED DEVIES FOUND
        if (addr == BH1750_I2C_ADDR)
        {
            init_bh1750(addr);
        }
        else if (addr == RTC_I2C_ADDR)
        {
            init_rtc_i2c(addr);
        }
        else if (addr == EEPROM_I2C_ADDR)
        {
            init_eeprom_i2c(addr);
        }
    }
}

void update_display_time(PicoLed::PicoLedController &_leds, const int _h, const int _m, const int _s)
{
    if (faceplate)
    {
        faceplate->display_time(_leds, _h, _m, _s);
    }
}

void display_ip(PicoLed::PicoLedController &_leds, const std::string _ip)
{
    const char *delim = ".";
    std::vector<std::string> out;
    helper::tokenize(_ip, delim, out);
    for (int i = 0; i < out.size(); i++)
    {
        // LIGHT UP FOR A IP BLOCK
        _leds.setBrightness(128);
        for (int j = 0; j < out.at(i).size(); j++)
        {
            if (faceplate)
            {
                const int ip_digit = (int)(out.at(i).at(j) - '0');
                faceplate->display_time(_leds, ip_digit, 0, (ip_digit * 1 / 255) % 60);
            }
            sleep_ms(1000);
        }
        // DARKEN = BETWEEN IP BLOCK
        _leds.setBrightness(10);
        sleep_ms(2000);
    }
    // RESTORE BRIGHTNESS
    _leds.setBrightness(last_brightness);
}

void set_brightnesmode(const std::string _payload)
{
    if (_payload.empty())
    {
        current_brightness_mode = 0;
    }
    current_brightness_mode = helper::limit(_payload, 0, 255);
    settings->write(settings_storage::SETTING_ENTRY::BRIGHTNESS, current_brightness_mode);
}

int set_faceplate(const int _fp)
{
    const int faceplate_index = helper::limit(_fp, 0, (int)wordclock_faceplate::FACEPLATES::TEST);
    switch_fp(faceplate, static_cast<wordclock_faceplate::FACEPLATES>(faceplate_index));
    return faceplate_index;
}

void set_faceplate_str(const std::string _payload)
{
    const int actual_fb = set_faceplate(helper::limit(_payload, 0, (int)wordclock_faceplate::FACEPLATES::TEST));
    settings->write(settings_storage::SETTING_ENTRY::FACEPLATE, actual_fb);
}

void set_displayorientation_str(const std::string _payload)
{
    wordclock_faceplate::config.flip_state = (bool)helper::limit(_payload, 0, 1);
    settings->write(settings_storage::SETTING_ENTRY::DISPLAYORIENTATION, (int)wordclock_faceplate::config.flip_state);
}

void set_displayorientation(const int _payload)
{
    wordclock_faceplate::config.flip_state = (bool)helper::limit(_payload, 0, 1);
    settings->write(settings_storage::SETTING_ENTRY::DISPLAYORIENTATION, (int)wordclock_faceplate::config.flip_state);
}

void set_time_from_wifi(const std::string _payload)
{
    if (ignore_wifi_time)
    {
        wifi_time_date_adjustment = 0;
        printf("wifi time update ignored\n");
        return;
    }

    int hour = 0;
    int minute = 0;
    int second = 0;
    if (!extract_time(_payload, hour, minute, second))
    {
        printf("invalid wifi time: %s\n", _payload.c_str());
        return;
    }

    int adjusted_minutes = (hour * 60) + minute + timezone_offset_minutes;
    wifi_time_date_adjustment = 0;
    if (adjusted_minutes < 0)
    {
        adjusted_minutes += 24 * 60;
        wifi_time_date_adjustment = -1;
    }
    else if (adjusted_minutes >= 24 * 60)
    {
        adjusted_minutes -= 24 * 60;
        wifi_time_date_adjustment = 1;
    }

    timekeeper->set_rtc_time(adjusted_minutes / 60, adjusted_minutes % 60, second, false);
}

void set_time_from_usb(const int _hour, const int _minute, const int _second)
{
    timekeeper->set_rtc_time(_hour, _minute, _second, false);
    display_update = true;
}

void set_date_from_wifi(const std::string _payload)
{
    int day = 0;
    int month = 0;
    int year = 0;
    if (!extract_date(_payload, day, month, year) || day > days_in_month(month, year))
    {
        printf("invalid wifi date: %s\n", _payload.c_str());
        return;
    }

    adjust_date(day, month, year, wifi_time_date_adjustment);
    timekeeper->set_rtc_date(day, month, year);
}

void set_date_from_usb(const std::string _payload)
{
    timekeeper->set_rtc_date(_payload);
    display_update = true;
}

void set_ignore_wifi_time(const bool _ignore)
{
    ignore_wifi_time = _ignore;
    settings->write(settings_storage::SETTING_ENTRY::IGNOREWIFITIME, (uint8_t)_ignore);
}

bool get_ignore_wifi_time()
{
    return ignore_wifi_time;
}

void set_timezone_offset(const int _offset_minutes)
{
    if (_offset_minutes < TIMEZONE_MINUTES_MIN ||
        _offset_minutes > TIMEZONE_MINUTES_MAX ||
        _offset_minutes % TIMEZONE_MINUTES_STEP != 0)
    {
        return;
    }
    timezone_offset_minutes = _offset_minutes;
    settings->write(settings_storage::SETTING_ENTRY::TIMEZONEOFFSET, encode_timezone_offset(_offset_minutes));
}

int get_timezone_offset()
{
    return timezone_offset_minutes;
}

void set_dls(const std::string _payload)
{
    const int v = (bool)helper::limit(_payload, 0, 1);
    timekeeper->set_daylightsaving(v);
    settings->write(settings_storage::SETTING_ENTRY::DAYLIGHTSAVING, v);
}

void set_dob(const std::string _payload)
{
    const int v = helper::limit(_payload, 0, 100);
    wordclock_faceplate::config.dotbrightness = v;
    settings->write(settings_storage::SETTING_ENTRY::DOTBRIGHTNESS, v);
}

void set_brightnesscurve(const std::string _payload)
{
    brighness_curve = helper::limit(_payload, 10, 100);
    settings->write(settings_storage::SETTING_ENTRY::BRIGHTNESSCURVE, brighness_curve);
}

void set_blinkendots(const std::string _payload)
{
    const bool v = (bool)helper::limit(_payload, 0, 1);
    wordclock_faceplate::config.blinkendots = v;
    settings->write(settings_storage::SETTING_ENTRY::BLINKENDOTS, v);
}

void set_colormode(const std::string _payload)
{
    const int colormode_index = helper::limit(_payload, 0, (int)wordclock_faceplate::COLORMODE::LENGTH);
    faceplate->set_colormode(static_cast<wordclock_faceplate::COLORMODE>(colormode_index));
    settings->write(settings_storage::SETTING_ENTRY::COLORMODE, (int)wordclock_faceplate::config.color_mode);
}

int apply_brightnesscurve(const int _in)
{
    // LINEAR IF brighness_curve <= 10
    if (brighness_curve < 11)
    {
        return _in;
    }
    // EXPONENTIAL IN 0.02 steps
    return helper::limit(std::pow(_in, 1 + (brighness_curve / 20.0)), WORDCLOCK_BRIGHTNESS_MODE_AUTO_MIN, WORDCLOCK_BRIGHTNESS_MODE_AUTO_MAX);
}

void prepare_display_ip(const std::string _payload)
{
    if (_payload.size() > 0)
    {
        display_to_ip = _payload;
    }
}

void restore_settings(bool _force = false)
{
    // USED TO CHECK VALUE OF SETTING_ENTRY::INVALID
    // IF VALUES ARENT MATCHING => ERASE FLASH/EEPROM
    // USE THE RP2040 CHIPID BECAUSE ITS DIFFERENT ON EACH BOARD SO A INITIAL WRITE WILL BE PERFORMED ON FIRST SW LOAD
    // ALSO ON EACH VERSION CHANGE OR PCB VERSION CHANGE A RESTORE SETTINGS WILL BE INITIATED USING VERSION AND WORDCLOCK_PCBREV DEFINED FROM CAMKE AND BOARD SETTINGS.h
    pico_unique_board_id_t chip_id;
    pico_get_unique_board_id(&chip_id);
    int versionint = 0;

#ifdef VERSION
    versionint = helper::version2int(VERSION);
#endif
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
int main()
{
    bool led_state = false;
    stdio_init_all();

    gpio_init(PICO_DEFAULT_LED_PIN);
    gpio_set_dir(PICO_DEFAULT_LED_PIN, GPIO_OUT);
    gpio_put(PICO_DEFAULT_LED_PIN, true);

    wordclock_faceplate::config = wordclock_faceplate::FACEPLATE_CONFIG();

    init_i2c();
    // AFTER CALLING init_i2c all needed instances of timekeeper lightsensor settings objects should be created.
    //  IF A I2C DEVICE ISNT PRESENT CREATE DEFAULT ONES
    if (!settings)
    {
#if defined(USE_FLASH_AS_EEPROM)
        settings = new settings_storage_flash();
#else
        settings = new settings_storage();
#endif
    }

    if (!timekeeper)
    {
#if defined(USE_RP2040RTC)
        timekeeper = new rtc_rp2040();
#else
        timekeeper = new rtc();
#endif
    }

    if (!lightsensor)
    {
        lightsensor = new ambient_light();
    }

    if (!settings || !timekeeper || !lightsensor)
    {
        while (1)
        {
            printf("init failed: settings_%i timekeeper_%i lightsensor_%i\n", settings, timekeeper, lightsensor);
            led_state = !led_state;
            gpio_put(PICO_DEFAULT_LED_PIN, led_state);
            sleep_ms(100);
        }
    }

    settings->init();
    timekeeper->init();
    lightsensor->init();

    // modified lib for 400khz
    PicoLed::PicoLedController ledStrip = PicoLed::addLeds<PicoLed::WS2812B>(pio0, 0, PICO_DEFAULT_WS2812_PIN, PICO_DEFAULT_WS2812_NUM, PicoLed::FORMAT_GRB);
    // set initial brightness
    ledStrip.clear();
    ledStrip.show();
    ledStrip.setBrightness(128);
    sleep_ms(500);
    // DISPLAY TESTPATTERN => light up all corners to test matrix settings
    faceplate->display_testpattern(ledStrip);
    sleep_ms(1000 + DEBUG * 5000);
    // current_brightness = lightsensor->get_brightness();
    // ledStrip.setBrightness(current_brightness);

    // enable uart rx irq for communication with wifi module and register callback functions
    wifi_interface::init_uart();
#ifdef ENABLE_UART_IRQ
    wifi_interface::enable_uart_irq(true);
#endif
    wifi_interface::register_rx_callback(set_time_from_wifi, wifi_interface::CMD_INDEX::TIME);
    wifi_interface::register_rx_callback(set_brightnesmode, wifi_interface::CMD_INDEX::BRIGHTNESS);
    wifi_interface::register_rx_callback(set_faceplate_str, wifi_interface::CMD_INDEX::FACEPLATE);
    wifi_interface::register_rx_callback(prepare_display_ip, wifi_interface::CMD_INDEX::DISPLAYIP);
    wifi_interface::register_rx_callback(set_displayorientation_str, wifi_interface::CMD_INDEX::DISPLAYORIENTATION);
    wifi_interface::register_rx_callback(set_dls, wifi_interface::CMD_INDEX::DAYLIGHTSAVING);
    wifi_interface::register_rx_callback(set_brightnesscurve, wifi_interface::CMD_INDEX::BRIGHTNESSCURVE);
    wifi_interface::register_rx_callback(set_date_from_wifi, wifi_interface::CMD_INDEX::DATE);
    wifi_interface::register_rx_callback(set_colormode, wifi_interface::CMD_INDEX::COLORMODE);
    wifi_interface::register_rx_callback(set_restoresettings, wifi_interface::CMD_INDEX::RESTORESETTINGS);
    wifi_interface::register_rx_callback(set_dob, wifi_interface::CMD_INDEX::DOTBRIGHTNESS);
    wifi_interface::register_rx_callback(set_blinkendots, wifi_interface::CMD_INDEX::BLINKENDOTS);

// RESTORE ALLE SETTINGS
//  DO ITS AT THE END (AFTER I2C INIT ) -> settings source could changesd to eeprom if enabled
#ifdef FORCE_RESTORE_SETTINGS
    restore_settings(true);
#else
    restore_settings(false);
#endif

    usb_serial_commandline::callbacks usb_callbacks;
    usb_callbacks.set_time = set_time_from_usb;
    usb_callbacks.set_date = set_date_from_usb;
    usb_callbacks.set_brightness = set_brightnesmode;
    usb_callbacks.display_ip = prepare_display_ip;
    usb_callbacks.set_faceplate = set_faceplate_str;
    usb_callbacks.set_orientation = set_displayorientation_str;
    usb_callbacks.set_brightness_curve = set_brightnesscurve;
    usb_callbacks.set_daylight_saving = set_dls;
    usb_callbacks.set_color_mode = set_colormode;
    usb_callbacks.restore_settings = set_restoresettings;
    usb_callbacks.set_dot_brightness = set_dob;
    usb_callbacks.set_blink_dots = set_blinkendots;
    usb_callbacks.set_ignore_wifi_time = set_ignore_wifi_time;
    usb_callbacks.get_ignore_wifi_time = get_ignore_wifi_time;
    usb_callbacks.set_timezone_offset = set_timezone_offset;
    usb_callbacks.get_timezone_offset = get_timezone_offset;
    usb_serial_commandline::init(usb_callbacks);

    gpio_put(PICO_DEFAULT_LED_PIN, false);


    
    while (true)
    {
        sleep_ms(10);

        usb_serial_commandline::process();

// PROCEESS ANY RECEIEVED COMMANDS
#ifndef ENABLE_UART_IRQ
        wifi_interface::on_wifi_uart_rx();
#endif
        wifi_interface::process_cmd();
        // SET UPDATE DISPLAY EVERY x00 MS
        const long long current_update = time_us_64();
        if (abs(last_update - current_update) > (300 * 1000))
        {
            last_update = current_update;
            display_update = true;
        }

        // UPDATE DISPLAY STUFF HERE
        if (display_update)
        {
            display_update = false;
            // DISPLAY IP IF NEEDED
            if (display_to_ip.size() > 0)
            {
                display_ip(ledStrip, display_to_ip);
                display_to_ip = "";
            }
            // UPDATE DISPLAY IF NEEDED
            const datetime_t t = timekeeper->read_rtc();
            if (last_tsec != t.sec)
            {
                last_tsec = t.sec;
                printf("h%i m%i s%i b%i d%i m%i y%i\n", t.hour, t.min, t.sec, current_brightness, t.day, t.month, t.year);
                update_display_time(ledStrip, t.hour, t.min, t.sec);
            }
            // CHECK BRIGHTNESS
            if (current_brightness_mode == 0)
            {
                const int sensor_read = apply_brightnesscurve(lightsensor->get_average_brightness()); // automatic if mode = 0
                if (sensor_read > current_brightness && current_brightness <= 255)
                {
                    current_brightness++;
                }
                else if (sensor_read < current_brightness && current_brightness > 11)
                {
                    current_brightness--;
                }
            }
            else
            {
                current_brightness = current_brightness_mode; // manual if mode 1-255
            }
            // UPDATE BRIGHTNESS IF NEEDED
            if (abs(current_brightness - last_brightness) > 0)
            {
                last_brightness = current_brightness;
                ledStrip.setBrightness(current_brightness);
#ifdef ENABLE_SMMOTH_FADE
                // UPDATE DISPLAY AGAIN TO APPLY NEW BRIGHTNESS
                update_display_time(ledStrip, t.hour, t.min, t.sec);
#endif
            }
        }
    }
    return 0;
}

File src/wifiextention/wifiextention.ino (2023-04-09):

//WORDCLOCK WIFI MODUL https://github.com/RBEGamer/WordClock/
//--- CHANGELOG ----
// 16.11.2022 -  INITIAL
// 25.12.2022 -  simplification due to more required parameters
// 25.12.2022 - due to storage working on the rp2040 with firmware V2 and working flash/eeporm storage the wifimodule doesnt save settings locally
// 27.12.2022 - added colormodes and clock reset command
#define VERSION "3.4.1"
// ENABLE ON ESP8266-01 !!!!!!!!!!!!!!!!!!!!!!!!!!
#define USE_LITTLEFS
//FOR ESP8266-01
#define LED_BUILTIN 2

#include <Arduino.h>
#include "FS.h"

#ifdef ESP8266
#include <ESP8266WiFi.h>
#include <ESP8266WebServer.h>
#include <ESP8266mDNS.h>
#endif

#ifdef ESP32
#include <WebServer.h>
#define FORMAT_SPIFFS_IF_FAILED true
#ifdef USE_LITTLEFS
#define SPIFFS LITTLEFS
#include <LITTLEFS.h>
#else
#include <SPIFFS.h>
#endif
#include <ESPmDNS.h>
#endif



#include <WiFiClient.h>
#include <WiFiUdp.h>
#include <TimeLib.h>
#include <NTPClient.h>
#include <WiFiManager.h>
#include <WiFiUdp.h>
#include <ArduinoOTA.h>


// CONFIG -------------------------------------
#define WEBSERVER_PORT 80                                     // set the port for the webserver eg 80 8080
#define MDNS_NAME "wordclock"                                 // set hostname
#define WEBSITE_TITLE "Word Clock Wifi Module Configuration"  // name your device
#define SERIAL_BAUD_RATE 9600
#define NTP_SEND_TIME_INTERVAL 5 * 60  //sende zeit an uhr all x minuten
#define DEFAULT_NTP_SERVER "pool.ntp.org"
#define DEFAULT_TIMEZONE 1
// END CONFIG ---------------------------------




String time_last = "not synced";
long last = 0;
long last_ee = 0;
#if defined(ESP8266)
const String BOARD_INFO = "WORDCLOCKWIFIMODULE_FW_" + String(VERSION) + "_BOARD_" + "ESP8266";
#elif defined(ESP32)
const String BOARD_INFO = "WORDCLOCKWIFIMODULE_FW_" + String(VERSION) + "_BOARD_" + "ESP32";
#endif


const String ap_name = "WordClockConfiguration";

// END NEOPIXEL CONF ---------------------------
//FILES FOR STORiNG CONFIGURATION DATA
const char* file_ntp_server = "/file.txt";
const char* file_timezone = "/timezone.txt";
//VARS

int timezone = 0;
String ntp_server_url = "pool.ntp.org";
String last_error = "";
int rtc_hours = 0;
int rtc_mins = 0;
int rtc_secs = 0;
int rtc_day = 1;
int rtc_month = 1;
int rtc_year = 2020;
int rtc_hours_tmp = 0;
//IS SET TO TRUE IN SETUP IF A RTC CLOCK IS DETECTED
//USEDE FOR SOFTWARE CLOCK
unsigned long timeNow = 0;
unsigned long timeLast = 0;


// INSTANCES --------------------------------------------

#ifdef ESP8266
ESP8266WebServer server(WEBSERVER_PORT);
#endif

#ifdef ESP32
WebServer server(WEBSERVER_PORT);
#endif

WiFiUDP ntpUDP;
NTPClient timeClient(ntpUDP, DEFAULT_NTP_SERVER, 0, 60000);
WiFiClient espClient;
WiFiManager wifiManager;






const String phead_1 = "<!DOCTYPE html><html><head><title>";
const String phead_2 = "</title>"
                       "<meta http-equiv='content-type' content='text/html; charset=utf-8'>"
                       "<meta charset='utf-8'>"
                       "<link "
                       "href='http://ajax.googleapis.com/ajax/libs/jqueryui/1.8.16/themes/base/"
                       "jquery-ui.css' rel=stylesheet />"
                       "<script "
                       "src='http://ajax.googleapis.com/ajax/libs/jquery/1.6.4/jquery.min.js'></"
                       "script>"
                       "<script "
                       "src='http://ajax.googleapis.com/ajax/libs/jqueryui/1.8.16/"
                       "jquery-ui.min.js'></script>"
                       "<style>"
                       "html, body {"
                       "  background: #F2F2F2;"
                       " width: 100%;"
                       " height: 100%;"
                       " margin: 0px;"
                       " padding: 0px;"
                       " font-family: 'Verdana';"
                       " font-size: 16px;"
                       " color: #404040;"
                       " }"
                       "img {"
                       " border: 0px;"
                       "}"
                       "span.title {"
                       " display: block;"
                       " color: #000000;"
                       " font-size: 30px;"
                       "}"
                       "span.subtitle {"
                       " display: block;"
                       " color: #000000;"
                       " font-size: 20px;"
                       "}"
                       ".sidebar {"
                       " background: #FFFFFF;"
                       " width: 250px;"
                       " min-height: 100%;"
                       " height: 100%;"
                       " height: auto;"
                       " position: fixed;"
                       " top: 0px;"
                       " left: 0px;"
                       " border-right: 1px solid #D8D8D8;"
                       "}"
                       ".logo {"
                       " padding: 25px;"
                       " text-align: center;"
                       " border-bottom: 1px solid #D8D8D8;"
                       "}"
                       ".menu {"
                       " padding: 25px 0px 25px 0px;"
                       " border-bottom: 1px solid #D8D8D8;"
                       "}"
                       ".menu a {"
                       " padding: 15px 25px 15px 25px;"
                       " display: block;"
                       " color: #000000;"
                       " text-decoration: none;"
                       " transition: all 0.25s;"
                       "}"
                       ".menu a:hover {"
                       " background: #0088CC;"
                       " color: #FFFFFF;"
                       "}"
                       ".right {"
                       " margin-left: 250px;"
                       " padding: 50px;"
                       "}"
                       ".content {"
                       " background: #FFFFFF;"
                       " padding: 25px;"
                       " border-radius: 5px;"
                       " border: 1px solid #D8D8D8;"
                       "}"
                       "</style>";

const String pstart = "</head>"
                      "<body style='font-size:62.5%;'>"
                      "<div class='sidebar'>"
                      "<div class='logo'>"
                      "<span class='title'>WordCLock - WIFI MODULE</span>"
                      "<span class='subtitle'>- Configuration -</span>"
                      "</div>"
                      "<div class='menu'>"
                      "<a href='index.html'>Settings</a>"
                      "</div>"
                      "</div>"
                      "<div class='right'>"
                      "<div class='content'>";

const String pend = "</div></div></body></html>";
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

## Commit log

2022-11-20 wifi interface
    added wifi interface
    hour +1 fix
    tokenize
    [helper.cpp, main.cpp, wifi_interface.cpp]
2022-11-27 added pcb v2
    [BOM_PCB_wordclocksmall_2022-11-27.csv, BOM_wordclocksmall_2022-11-27.csv, PCB_wordclocksmall_2022-11-27.dxf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]
2022-11-28 fixed track lenght drc
2022-12-12 added boardef for rotated
2022-12-23 dfx generated for 14x14mm spacers
    [0_opaque_layer.dxf, 1_textgerman_layer.dxf, 2_lightguidehexnut_layer.dxf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]
2022-12-23 fixed dfx
    [0_opaque_layer.dxf, 1_textgerman_layer.dxf, 2_lightguidehexnut_layer.dxf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]
2022-12-27 BH1750 BUG ADDED
    strange bug with bh1750 if i2c detects address its not possible to delete old instance of the class
    [WORDCLOCK_V2_RP2040.h, ambient_light_bh1750.cpp, main.cpp]
2022-12-28 first default settins write bug...
    [WORDCLOCK_V2_RP2040.h, main.cpp]
2023-01-12 add italian fontface
    [1_textitalian_layer.dxf]
2023-01-12 added en fontface
    [1_textenglish_layer.dxf]
2023-01-15 added 3d printable wallmount and tablstand
    [wordclock_tablestand.f3d, wordclock_tablestand.step, wordclock_tablestand.stl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]
2023-01-20 fixed en it svg
    [1_textenglish_layer.dxf, 1_textitalian_layer.dxf]
2023-01-23 added am/pm fontface as option
    [1_textenglish_am_pm_layer.dxf]
2023-01-23 english fontface fully fixed
    [main.cpp]
2023-02-03 aded v3 pcb (testing needed)
    [BOM_PCB_wordclocksmall_2023-02-03.csv, PCB_wordclocksmall_2023-02-03.dxf, PCB_wordclocksmall_2023-02-03.pcbdoc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]
2023-02-03 added led2 fix pcf8574
    [BOM_PCB_wordclocksmall_2023-02-03.csv, PCB_wordclocksmall_2023-02-03.dxf, PCB_wordclocksmall_2023-02-03.pcbdoc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]
2023-02-03 [NOT WORKING] working on code for PCBv3
    [main.cpp]
2023-04-09 german fontface ü fixed
    [1_textgerman_layer.dxf]
2023-04-09 SW FIXES 3.4.1
    * fixing auto mode
    * fixing curve mode
    * added options for blinkendots
    * added options for dimmable minute dots
    * added colors to ip display block
    [WORDCLOCK_V2_RP2040.h, WORDCLOCK_V2_RP2040_NOI2C.h, WORDCLOCK_V2_RP2040_RP2040RTC.h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]
2023-04-09 fixing dls, new wifiinterface command lut
    [main.cpp, wifi_interface.cpp, wifiextention.ino]
